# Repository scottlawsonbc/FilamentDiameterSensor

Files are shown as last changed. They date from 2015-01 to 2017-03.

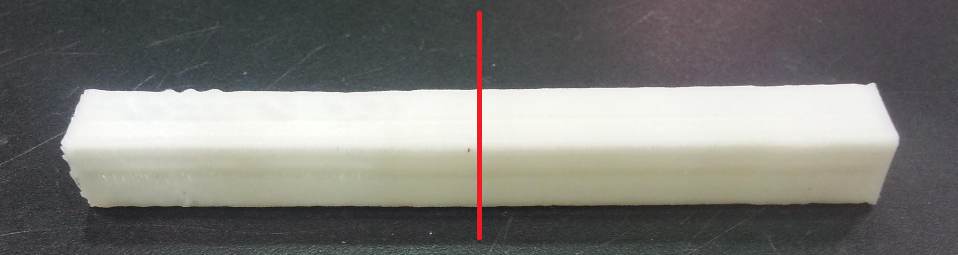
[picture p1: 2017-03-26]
pictures/surface-finish-quality-print.png

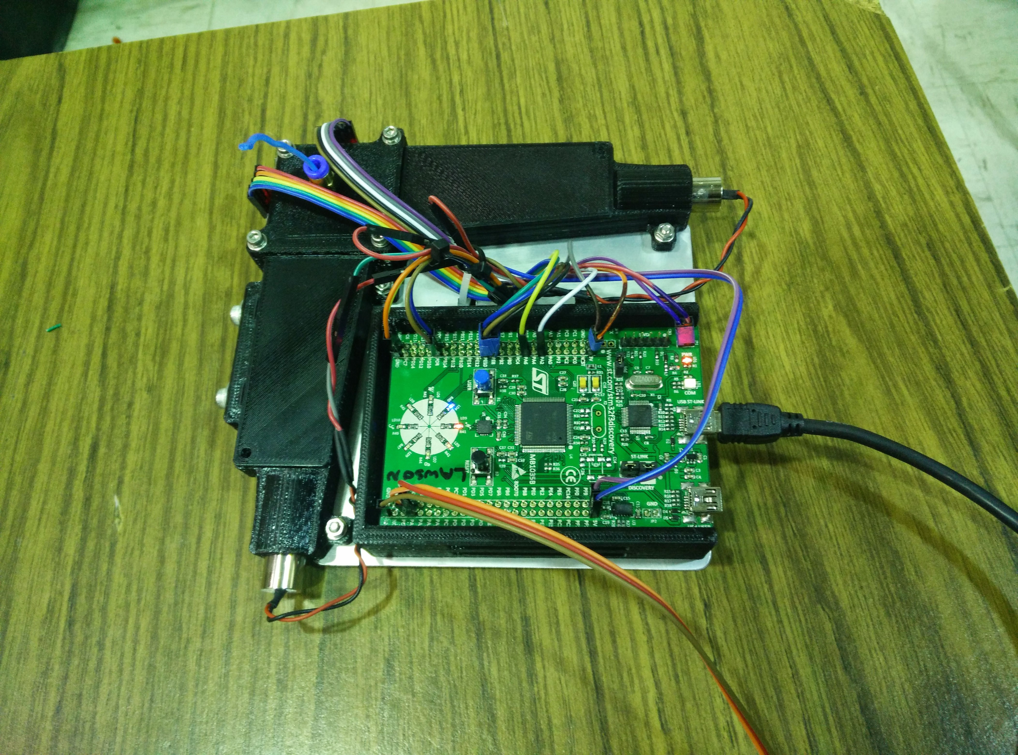
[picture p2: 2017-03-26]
pictures/printer-integrated-unattached.jpg

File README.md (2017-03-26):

# FilamentDiameterSensor

ENPH 459 - Engineering Physics Project I
----------------------------------------
A Non-contact Diameter Measurement Device for 3D Printers and Filament Manufacturing

### File Organization ###

1.  *Arduino* - 
    Initial prototype was implemented for Arduino.

2.  *Code* - 
    Includes the rest of the project's (non-MATLAB) code. Several versions of the shadow-simulator, a fork of the printer firmware Marlin(modified to interface with the filament sensor), and the sensor's firmware to be run on a STM32F3 development board.
    
3.  *Eagle* - 
    PCB layout files for the photodiode array (TSL1402CL) breakout board.
    
4.  *Matlab* - 
    Matlab script used to measure the relative print quality based on the roughness of vertical printed edges.

5.  *Pictures* - 
    Pictures from the sensor development and print quality testing.

6.  *Reference Documents* - 
    Documentation for the STM32F3 development board, the linear photodiode array used in the sensor, and the prototype sensor.
    
7.  *Solidworks* - 
    All 3D design for the sensor, mostly Solidworks with some .STL-rasterized models for 3D printing.

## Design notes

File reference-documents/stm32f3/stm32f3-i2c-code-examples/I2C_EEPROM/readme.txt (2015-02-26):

/**
  @page I2C_EEPROM  How to use the I2C to drive an EEPROM memory
  
  @verbatim
  ******************** (C) COPYRIGHT 2014 STMicroelectronics *******************
  * @file    I2C/I2C_EEPROM/readme.txt 
  * @author  MCD Application Team
  * @version V1.1.1
  * @date    31-October-2014
  * @brief   Description of the I2C and M24Mxx or M24Lxx EEPROM communication example.
  ******************************************************************************
  *
  * Licensed under MCD-ST Liberty SW License Agreement V2, (the "License");
  * You may not use this file except in compliance with the License.
  * You may obtain a copy of the License at:
  *
  *        http://www.st.com/software_license_agreement_liberty_v2
  *
  * Unless required by applicable law or agreed to in writing, software 
  * distributed under the License is distributed on an "AS IS" BASIS, 
  * WITHOUT WARRANTIES OR CONDITIONS OF ANY KIND, either express or implied.
  * See the License for the specific language governing permissions and
  * limitations under the License.
  *   
  ******************************************************************************
   @endverbatim

@par Example Description 

This firmware provides a basic example of how to use the I2C firmware library and
an associate I2C EEPROM driver to communicate with an I2C EEPROM device (here the
example is interfacing with M24M01 or M24LR64 EEPROM)

I2C peripheral is configured in Master transmitter during write operation and in
Master receiver during read operation from I2C EEPROM. 

The peripheral used is I2C2 but can be configured by modifying the defines values
in stm32303c_eval.h file.
The maximum speed of communication with M24M01 EEPROM is 1MHz and with M24LR64 is 400kHz.
The speed of communication is configured by setting the value of sEE_I2C_TIMING define
in stm32303c_eval_i2c_ee.h file.

For M24M01 devices all the memory is accessible through the two-bytes 
addressing mode and need to define block addresses. In this case, the physical 
address has to be defined according to the address pins (E0, E1) connection) and
memory block address (A16).

For M24LR64 devices all the memory is accessible through the two-bytes 
addressing mode and need to define block addresses. In this case, the physical 
address has to be defined according to the address pins (E1, E2) connection.

This address is defined in stm32303c_eval_i2c_ee.h. 
The EEPROM addresses where the program start the write and the read operations 
is defined in the main.c file. 

First, the content of Tx1Buffer is written to the sEE_WRITE_ADDRESS1 and the
written data are read. The written and the read buffers data are then compared.
Following the read operation, the program waits that the EEPROM reverts to its 
Standby state. A second write operation is, then, performed and this time, Tx2Buffer
is written to sEE_WRITE_ADDRESS2 which represents the address just after the last 
written one in the first write. After completion of the second write operation, the 
written data are read. The contents of the written and the read buffers are compared.

All transfers are managed in Polling mode by calling sEE_ReadBuffer() or 
sEE_WriteBuffer() function.

User should refer to stm32303c_eval.h file to select which EEPROM use in this example.
    
This example provides the possibility to use the LCD screen for messages display
(transfer status: Ongoing, PASSED, FAILED).
To enable this option uncomment the define ENABLE_LCD_MSG_DISPLAY in the main.c
file.

Note : By Default this example is configured to run with M24LR64 EEPROM. Refer to 
       stm32303c_eval_i2c_ee.h file to change supported EEPROM and update the
       I2C_TIMING. 
       
@par Directory contents 

  - I2C/I2C_EEPROM/stm32f30x_conf.h    Library Configuration file
  - I2C/I2C_EEPROM/stm32f30x_it.c      Interrupt handlers
  - I2C/I2C_EEPROM/stm32f30x_it.h      Interrupt handlers header file
  - I2C/I2C_EEPROM/main.c              Main program
  - I2C/I2C_EEPROM/main.h              Main program header file   
  - I2C/I2C_EEPROM/system_stm32f30x.c  STM32F30x system source file
  
@note The "system_stm32f30x.c" is generated by an automatic clock configuration 
      system and can be easily customized to your own configuration. 
      To select different clock setup, use the "STM32F30x_Clock_Configuration_V1.0.0.xls" 
      provided with the AN4152 package available on <a href="http://www.st.com/internet/mcu/family/141.jsp">  ST Microcontrollers </a>
      
@par Hardware and Software environment

  - This example runs on STM32F30x Devices.
  
  - This example has been tested with STMicroelectronics STM32303C-EVAL (STM32F30x)
    evaluation board and can be easily tailored to any other supported device 
    and development board. 

  - STM32303C-EVAL Set-up
    - When communicating with M24LR64 EEPROM, make sure that M24LR64 is inserted in CN1 connector and 
      JP5 and JP6 jumpers are fitted in position 1-2.
    - When communicating with M24M01 EEPROM, make sure that JP5 and JP6 jumpers are fitted in position 2-3
      and JP8 is fitted.
    
@par How to use it ? 

In order to make the program work, you must do the following :
 - Copy all source files from this example folder to the template folder under
   Projects\STM32F30x_StdPeriph_Templates
 - Open your preferred toolchain
 - Add the following file the project source list
    - Utilities\STM32_EVAL\STM32303C_EVAL\stm32303c_eval.c
    - Utilities\STM32_EVAL\STM32303C_EVAL\stm32303c_eval_lcd.c
    - Utilities\STM32_EVAL\STM32303C_EVAL\stm32303c_eval_i2c_ee.c
 - Before building the project please make sure that "USE_DEFAULT_TIMEOUT_CALLBACK" 
   define is removed from Preprocessor defines under C/C++ compiler settings.  
 - Rebuild all files and load your image into target memory
 - Run the example
    
 * <h3><center>&copy; COPYRIGHT STMicroelectronics</center></h3>
 */

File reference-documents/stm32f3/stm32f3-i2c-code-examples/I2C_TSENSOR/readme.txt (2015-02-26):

/**
  @page I2C_TSENSOR Communication between I2C and STTS751 Temperature sensor
  
  @verbatim
  ******************** (C) COPYRIGHT 2014 STMicroelectronics *******************
  * @file    I2C/I2C_TSENSOR/readme.txt 
  * @author  MCD Application Team
  * @version V1.1.1
  * @date    31-October-2014
  * @brief   Description of the I2C TSENSOR example.
  ******************************************************************************
  *
  * Licensed under MCD-ST Liberty SW License Agreement V2, (the "License");
  * You may not use this file except in compliance with the License.
  * You may obtain a copy of the License at:
  *
  *        http://www.st.com/software_license_agreement_liberty_v2
  *
  * Unless required by applicable law or agreed to in writing, software 
  * distributed under the License is distributed on an "AS IS" BASIS, 
  * WITHOUT WARRANTIES OR CONDITIONS OF ANY KIND, either express or implied.
  * See the License for the specific language governing permissions and
  * limitations under the License.
  *   
  ******************************************************************************
   @endverbatim

@par Example Description 

This example provides a description of how to use the I2C to communicate with 
an STTS751 (or a compatible device) I2C temperature sensor is mounted on the 
STM32303C-EVAL board and used to get instantaneous external temperature (-55°C to +125°C).
 
Thanks to STM32 I2C SMBus feature, we can easily monitor the temperature 
variations. This is managed by the SMBus Alert which is generating a dedicated 
interrupt informing the system that the temperature is out of the selected 
ranges.
The user can configure the TOS and THYS thanks to a dedicated define values in 
the code.

By default the STM32303C-EVAL demo are setting them to (see main.c file):
  
#define TEMPERATURE_THYS        0x14 /* 20°C */
#define TEMPERATURE_TOS         0x28 /* 40°C */

@par Directory contents 

  - I2C/I2C_TSENSOR/stm32f30x_conf.h    Library Configuration file
  - I2C/I2C_TSENSOR/stm32f30x_it.c      Interrupt handlers
  - I2C/I2C_TSENSOR/stm32f30x_it.h      Interrupt handlers header file
  - I2C/I2C_TSENSOR/main.c              Main program
  - I2C/I2C_TSENSOR/main.h              Main program header file   
  - I2C/I2C_TSENSOR/system_stm32f30x.c  STM32F30x system source file
  
@note The "system_stm32f30x.c" is generated by an automatic clock configuration 
      system and can be easily customized to your own configuration. 
      To select different clock setup, use the "STM32F30x_Clock_Configuration_V1.0.0.xls" 
      provided with the AN4152 package available on <a href="http://www.st.com/internet/mcu/family/141.jsp">  ST Microcontrollers </a>
         
@par Hardware and Software environment

  - This example runs on STM32F30x Devices.
  
  - This example has been tested with STMicroelectronics STM32303C-EVAL (STM32F30x)
    evaluation board and can be easily tailored to any other supported device 
    and development board. 

  - STM32303C-EVAL Set-up
    - Make sure that JP5 and JP6 jumpers are fitted in position 2-3.
    - Make sure that JP1 jumper is fitted.
    
@par How to use it ? 

In order to make the program work, you must do the following :
 - Copy all source files from this example folder to the template folder under
   Projects\STM32F30x_StdPeriph_Templates
 - Open your preferred toolchain 
 - Add the following file the project source list
    - Utilities\STM32_EVAL\STM32303C_EVAL\stm32303c_eval.c
    - Utilities\STM32_EVAL\STM32303C_EVAL\stm32303c_eval_lcd.c
    - Utilities\STM32_EVAL\STM32303C_EVAL\stm32303c_eval_i2c_tsensor.c
 - Before building the project please make sure that "USE_DEFAULT_TIMEOUT_CALLBACK" 
   define is removed from Preprocessor defines under C/C++ compiler settings. 
 - Rebuild all files and load your image into target memory
 - Run the example
   
 * <h3><center>&copy; COPYRIGHT STMicroelectronics</center></h3>
 */

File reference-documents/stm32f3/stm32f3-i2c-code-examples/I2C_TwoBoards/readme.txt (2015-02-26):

/**
  @page I2C_TwoBoards  I2C Communication Boards Data Exchange using CPAL Library
  
  @verbatim
  ******************** (C) COPYRIGHT 2014 STMicroelectronics *******************
  * @file    I2C/I2C_TwoBoards/readme.txt 
  * @author  MCD Application Team
  * @version V1.1.1
  * @date    31-October-2014
  * @brief   Description of the CPAL Two Boards communication example.
  ******************************************************************************
  *
  * Licensed under MCD-ST Liberty SW License Agreement V2, (the "License");
  * You may not use this file except in compliance with the License.
  * You may obtain a copy of the License at:
  *
  *        http://www.st.com/software_license_agreement_liberty_v2
  *
  * Unless required by applicable law or agreed to in writing, software 
  * distributed under the License is distributed on an "AS IS" BASIS, 
  * WITHOUT WARRANTIES OR CONDITIONS OF ANY KIND, either express or implied.
  * See the License for the specific language governing permissions and
  * limitations under the License.
  *   
  ******************************************************************************
   @endverbatim

@par Example Description 

This example shows how to use the CPAL library to control I2C devices and 
communicate between two different boards.

To use this example, you need to load the same software into two STM32 boards
(let's call them  Board A and Board B) then connect these two boards through I2C
lines and Gnd.

*------------------------------------------------------------------------------*
|                BOARD A                                BOARD B                |
|         ____________________                   ____________________          |
|        |                    |                 |                    |         |
|        |                    |                 |                    |         | 
|        |     __________     |                 |     __________     |         |
|        |    |I2C Device|____|_______SCL_______|____|I2C Device|    |         |
|        |    |__________|____|_______SDA_______|____|__________|    |         |
|        |                    |                 |                    |         |
|        |                    |                 |                    |         |
|        |  LEFT       RIGHT  |                 |  LEFT       RIGHT  |         |
|        |   _           _    |                 |   _           _    |         |
|        |  |_|         |_|   |                 |  |_|         |_|   |         |
|        |                    |                 |                    |         |
|        |             GND O--|-----------------|--O GND             |         |
|        |____________________|                 |____________________|         |
|                                                                              |
|                                                                              |
*------------------------------------------------------------------------------*

The example software perform the following actions:
 - At startup, Boards A & B are both in slave receiver mode and wait for messages 
   to be received.
 - When a push button is pressed, for example on Board A, the master transmitter 
   mode is activated and a message is sent to Board B containing identification 
   of the action relative to the push button.
 - Once a message is correctly sent, Board A activates the master transmitter mode 
   permanently and disables the slave receiver mode.
 - Once a message is received and correctly recognized, Board B activate the
   receiver mode and disable the transmitter mode. (push buttons interrupts are
   still active but message sending is disabled).
 - According to the push button pressed, a value is affected to a Timer which 
   generates periodic high priority interrupts. At each interrupt, a status message
   is sent to Board B. The period of Timer interrupts is variable depending on
   the push button pressed.    
 - When LEFT is pressed Board A send specific message (tSignal1) to Board B and set 
   the period of Timer to 1.5 seconds. When RIGHT is pressed specific message (tSignal2)
   is sent and the period of Timer is set to 0.305 seconds.

For each event (message received, message transmitted, error occur ...) a 
relative information is displayed on the LCD screen. When the same event is 
repeated, the line color is switched to highlight the event occurrence.

the Mode of Board (transmitter or receiver) is monitored by LEDs:
      - LED2 is toggling when transmitter mode is activated.
      - LED3 is toggling when receiver mode is activated. 

LED1 and LED4 are toggling by an interrupt generated by TIM6 each 50ms.

The programming model of I2C communication can be selected (DMA or Interrupt) in 
cpal_conf.h file by commenting or uncommenting these defines in Section 2 (Transfer
Options Configuration):
              #define CPAL_I2C_DMA_PROGMODEL
              #define CPAL_I2C_IT_PROGMODEL
Note : Only one define must selected. If these two defines are uncommented DMA Programming 
model is selected and the code size of this example will increase.

** UserCallbacks :

   - CPAL_TIMEOUT_UserCallback : This Callback is called to manage timeout error.
      In this Callback I2C device is reinitialized.
      
   - CPAL_I2C_ERR_UserCallback : This Callback is called to manage Device error .  
      In this Callback I2C device is reinitialized.
      Note: 
      If you want to generate an I2C error, you can disconnect I2C_SCL/I2C_SDA connector.
      In this case the I2C communication will be corrupted and the CPAL I2C error callbacks
      will be entered. If you fit back the jumper or connector, the communication should be 
      recovered immediately thanks to CPAL error management. 
      
   - CPAL_I2C_TXTC_UserCallback : This Callback is called when Write operation 
      is completed. In this Callback only information relative to communication 
      are displayed on LCD screen.
      
   - CPAL_I2C_RXTC_UserCallback : This Callback is called when Read operation 
      is completed. In this Callback received data are compared and transfer 
      status is displayed on LCD screen.

@par Directory contents 

  - I2C/I2C_TwoBoards/stm32f30x_conf.h                   Library Configuration file
  - I2C/I2C_TwoBoards/stm32f30x_it.c                     Interrupt handlers
  - I2C/I2C_TwoBoards/stm32f30x_it.h                     Interrupt handlers header file
  - I2C/I2C_TwoBoards/main.c                             Main program
  - I2C/I2C_TwoBoards/main.h                             Main program header file   
  - I2C/I2C_TwoBoards/system_stm32f30x.c                 STM32F30x system source file
  - I2C/I2C_TwoBoards/stm32f30x_i2c_cpal_conf.h          CPAL Library Configuration file
  - I2C/I2C_TwoBoards/stm32f30x_i2c_cpal_usercallback.c  CPAL Usercallbacks definition
  
@note The "system_stm32f30x.c" is generated by an automatic clock configuration 
      system and can be easily customized to your own configuration. 
      To select different clock setup, use the "STM32F30x_Clock_Configuration_V1.0.0.xls" 
      provided with the AN4152 package available on <a href="http://www.st.com/internet/mcu/family/141.jsp">  ST Microcontrollers </a>
        
@par Hardware and Software environment

  - This example runs on STM32F30x Devices.
  
  - This example has been tested with STMicroelectronics STM32303C-EVAL (STM32F30x)
    evaluation board and can be easily tailored to any other supported device 
    and development board. 

 - The same example should be loaded in two evaluation boards.
    
 - STM32303C-EVAL Set-up :
   Then these two boards should be connected as follows:
     - Connect I2C2 SCL pin (PF6) to I2C2 SCL pin (PF6)
     - Connect I2C2 SDA pin (PA10) to I2C2 SDA pin (PA10)
     - Connect Gnd pins of two boards.
    
@par How to use it ? 

In order to make the program work, you must do the following :
 - Copy all source files from this example folder to the template folder under
   Projects\STM32F30x_StdPeriph_Templates
 - Open your preferred toolchain 
 - Add the following files the project source list
     - Libraries\STM32F30x_I2C_CPAL_Driver\src\stm32f30x_i2c_cpal.c
     - Libraries\STM32F30x_I2C_CPAL_Driver\src\stm32f30x_i2c_cpal_hal.c
     - Projects\STM32F30x_StdPeriph_Templates\stm32f30x_i2c_cpal_usercallback.c
     - Utilities\STM32_EVAL\STM32303C_EVAL\stm32303c_eval.c
     - Utilities\STM32_EVAL\STM32303C_EVAL\stm32303c_eval_lcd.c
 - Rebuild all files and load your image into target memory
 - Run the example
    
 * <h3><center>&copy; COPYRIGHT STMicroelectronics</center></h3>
 */

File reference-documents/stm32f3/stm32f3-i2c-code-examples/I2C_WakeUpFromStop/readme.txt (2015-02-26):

/**
  @page I2C_WakeUpFromStop I2C WakeUp from stop mode
  
  @verbatim
  ******************** (C) COPYRIGHT 2014 STMicroelectronics *******************
  * @file    I2C/I2C_WakeUpFromStop/readme.txt 
  * @author  MCD Application Team
  * @version V1.1.1
  * @date    31-October-2014
  * @brief   Description of the Wake Up from Stop mode example.
  ******************************************************************************
  *
  * Licensed under MCD-ST Liberty SW License Agreement V2, (the "License");
  * You may not use this file except in compliance with the License.
  * You may obtain a copy of the License at:
  *
  *        http://www.st.com/software_license_agreement_liberty_v2
  *
  * Unless required by applicable law or agreed to in writing, software 
  * distributed under the License is distributed on an "AS IS" BASIS, 
  * WITHOUT WARRANTIES OR CONDITIONS OF ANY KIND, either express or implied.
  * See the License for the specific language governing permissions and
  * limitations under the License.
  *
  ******************************************************************************
  @endverbatim

@par Example Description 

This example shows how to use the WakeUp from STOP feature of I2C device using 
the CPAL library. This example requires two boards, one configured in master mode
and another one configured in slave mode.

The I2C of the slave board is configured as slave device which enters in STOP mode
after activating The WakeUp from stop ability. 

The master board is used to WakeUp the slave board from STOP. By pushing the key Button
of the master board, the I2C device initialize a communication by sending a Start condition
followed by the address of slave device. 

The slave device is woken Up from STOP if it recognizes its own address. 
The received data is checked and the result is displayed on LCD. 

This procedure is repeated infinitely.

The main.h file contains defines(I2C_MASTER, I2C_SLAVE) that select the type of 
the board(master or slave).

Note: Before entering STOP The I2C clock source must be set to HSI.

@par Directory contents 

  - I2C/I2C_WakeUpFromStop/stm32f30x_conf.h                    Library Configuration file
  - I2C/I2C_WakeUpFromStop/stm32f30x_it.c                      Interrupt handlers
  - I2C/I2C_WakeUpFromStop/stm32f30x_it.h                      Interrupt handlers header file
  - I2C/I2C_WakeUpFromStop/main.c                              Main program
  - I2C/I2C_WakeUpFromStop/main.h                              Main program header file 
  - I2C/I2C_WakeUpFromStop/system_stm32f30x.c                  STM32F30x system source file
  - I2C/I2C_TwoBoards/stm32f30x_i2c_cpal_conf.h                CPAL Library Configuration file
  - I2C/I2C_WakeUpFromStop/stm32f30x_i2c_cpal_usercallback.c   CPAL UserCallback source file
  
@note The "system_stm32f30x.c" is generated by an automatic clock configuration 
      system and can be easily customized to your own configuration. 
      To select different clock setup, use the "STM32F30x_Clock_Configuration_V1.0.0.xls" 
      provided with the AN4152 package available on <a href="http://www.st.com/internet/mcu/family/141.jsp">  ST Microcontrollers </a>
   
@par Hardware and Software environment

  - This example runs on STM32F30x Devices.
  
  - This example has been tested with STMicroelectronics STM32303C-EVAL (STM32F30x)
    evaluation board and can be easily tailored to any other supported device 
    and development board.

  - STM32303C-EVAL Set-up
    - Two boards must be used to run this example. The type of the board is selected
      by comments or uncomments defines (I2C_MASTER, I2C_SLAVE) located in main.h file.
    - These two boards should be connected as follow after loading the example:
     - Connect I2C2 SCL pin (PF6) to I2C2 SCL pin (PF6)
     - Connect I2C2 SDA pin (PA10) to I2C2 SDA pin (PA10)
     - Connect Gnd pins of two boards.
    - Make sure that JP5 and JP6 jumpers are fitted in position 2-3.

@par How to use it ? 

In order to make the program work, you must do the following :
 - Copy all source files from this example folder to the template folder under
   Projects\STM32F30x_StdPeriph_Templates
 - Open your preferred toolchain
 - Add the following files the project source list
     - Libraries\STM32F30x_I2C_CPAL_Driver\src\stm32f30x_i2c_cpal.c
     - Libraries\STM32F30x_I2C_CPAL_Driver\src\stm32f30x_i2c_cpal_hal.c
     - Projects\STM32F30x_StdPeriph_Templates\stm32f30x_i2c_cpal_usercallback.c
     - Utilities\STM32_EVAL\STM32303C_EVAL\stm32303c_eval.c
     - Utilities\STM32_EVAL\STM32303C_EVAL\stm32303c_eval_lcd.c  
 - Rebuild all files and load your image into target memory
 - Run the example

 * <h3><center>&copy; COPYRIGHT STMicroelectronics</center></h3>
 */

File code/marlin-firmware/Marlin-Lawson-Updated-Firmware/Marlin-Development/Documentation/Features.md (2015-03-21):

# Features

*   Interrupt based movement with real linear acceleration
*   High steprate
*   Look ahead (Keep the speed high when possible. High cornering speed)
*   Interrupt based temperature protection
*   Preliminary support for [Matthew Roberts Advance Algorithm](http://reprap.org/pipermail/reprap-dev/2011-May/003323.html)
*   Full endstop support
*   SD Card support
*   SD Card folders (works in pronterface)
*   SD Card autostart support
*   LCD support (ideally 20x4)
*   LCD menu system for autonomous SD card printing, controlled by an click-encoder.
*   EEPROM storage of e.g. max-velocity, max-acceleration, and similar variables
*   many small but handy things originating from bkubicek's fork.
*   Arc support
*   Temperature oversampling
*   Dynamic Temperature setpointing aka "AutoTemp"
*   Support for [QTMarlin](https://github.com/bkubicek/QTMarlin), a very beta GUI for PID-tuning and velocity-acceleration testing. 
*   Endstop trigger reporting to the host software.
*   Updated sdcardlib
*   Heater power reporting. Useful for PID monitoring.
*   PID tuning
*   [CoreXY kinematics](www.corexy.com/theory.html)
*   Delta kinematics
*   SCARA kinematics
*   Dual X-carriage support for multiple extruder systems
*   Configurable serial port to support connection of wireless adaptors.
*   Automatic operation of extruder/cold-end cooling fans based on nozzle temperature
*   RC Servo Support, specify angle or duration for continuous rotation servos.
*   Bed Auto Leveling.
*   Support for a filament diameter sensor, which adjusts extrusion volume

The default baudrate is 250000. This baudrate has less jitter and hence errors than the usual 115200 baud, but is less supported by drivers and host-environments.

## Differences and additions to the already good Sprinter firmware

### Look-ahead

Marlin has look-ahead. While sprinter has to break and re-accelerate at each corner,
lookahead will only decelerate and accelerate to a velocity,
so that the change in vectorial velocity magnitude is less than the xy_jerk_velocity.
This is only possible, if some future moves are already processed, hence the name.
It leads to less over-deposition at corners, especially at flat angles.

### Arc support

Slic3r can find curves that, although broken into segments, were ment to describe an arc.
Marlin is able to print those arcs. The advantage is the firmware can choose the resolution,
and can perform the arc with nearly constant velocity, resulting in a nice finish.
Also, less serial communication is needed.

### Temperature Oversampling

To reduce noise and make the PID-differential term more useful, 16 ADC conversion results are averaged.

### AutoTemp

If your gcode contains a wide spread of extruder velocities, or you realtime change the building speed, the temperature should be changed accordingly.
Usually, higher speed requires higher temperature.
This can now be performed by the AutoTemp function
By calling M109 S<mintemp> B<maxtemp> F<factor> you enter the autotemp mode.

You can leave it by calling M109 without any F.
If active, the maximal extruder stepper rate of all buffered moves will be calculated, and named "maxerate" [steps/sec].
The wanted temperature then will be set to t=tempmin+factor*maxerate, while being limited between tempmin and tempmax.
If the target temperature is set manually or by gcode to a value less then tempmin, it will be kept without change.
Ideally, your gcode can be completely free of temperature controls, apart from a M109 S T F in the start.gcode, and a M109 S0 in the end.gcode.

### EEPROM

If you know your PID values, the acceleration and max-velocities of your unique machine, you can set them, and finally store them in the EEPROM.
After each reboot, it will magically load them from EEPROM, independent what your Configuration.h says.

### LCD Menu

If your hardware supports it, you can build yourself a LCD-CardReader+Click+encoder combination. It will enable you to realtime tune temperatures,
accelerations, velocities, flow rates, select and print files from the SD card, preheat, disable the steppers, and do other fancy stuff.
One working hardware is documented here: http://www.thingiverse.com/thing:12663
Also, with just a 20x4 or 16x2 display, useful data is shown.

### SD card directories

If you have an SD card reader attached to your controller, also folders work now. Listing the files in pronterface will show "/path/subpath/file.g".
You can write to file in a subfolder by specifying a similar text using small letters in the path.
Also, backup copies of various operating systems are hidden, as well as files not ending with ".g".

### Autostart

If you place a file auto[0-9].g into the root of the sd card, it will be automatically executed if you boot the printer. The same file will be executed by selecting "Autostart" from the menu.
First *0 will be performed, than *1 and so on. That way, you can heat up or even print automatically without user interaction.

### Endstop trigger reporting

If an endstop is hit while moving towards the endstop, the location at which the firmware thinks that the endstop was triggered is outputed on the serial port.
This is useful, because the user gets a warning message.
However, also tools like QTMarlin can use this for finding acceptable combinations of velocity+acceleration.

### Coding paradigm

Not relevant from a user side, but Marlin was split into thematic junks, and has tried to partially enforced private variables.
This is intended to make it clearer, what interacts which what, and leads to a higher level of modularization.
We think that this is a useful prestep for porting this firmware to e.g. an ARM platform in the future.
A lot of RAM (with enabled LCD ~2200 bytes) was saved by storing char []="some message" in Program memory.
In the serial communication, a #define based level of abstraction was enforced, so that it is clear that
some transfer is information (usually beginning with "echo:"), an error "error:", or just normal protocol,
necessary for backwards compatibility.

### Interrupt based temperature measurements

An interrupt is used to manage ADC conversions, and enforce checking for critical temperatures.
This leads to less blocking in the heater management routine.

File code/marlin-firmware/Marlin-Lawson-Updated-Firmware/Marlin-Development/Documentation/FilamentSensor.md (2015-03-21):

Filament Sensor
---------------
Supports the use of a real time filament diameter sensor that measures the diameter of the filament going into the extruder and then adjusts the extrusion rate to compensate for filament that does not match what is defined in the g-code.  The diameter can also be displayed on the LCD screen. This potentially eliminates the need to measure filament diameter when changing spools of filament. Gcode becomes independent of the filament diameter. Can also compensate for changing diameter.

For examples of these sensors, see: http://www.thingiverse.com/thing:454584, https://www.youmagine.com/designs/filament-diameter-sensor, http://diy3dprinting.blogspot.com/2014/01/diy-filament-diameter-sensor.html. Any sensor which produces a voltage equivalent to the diameter in mm (i.e. 1v = 1mm) can be used. This provides a very simple interface and may encourage more innovation in this area.

4 new Mcodes are defined to set relevant parameters: M404, M405, M406, M407 - see above.

 Implements a delay buffer to handle the transit delay between where the filament is measured and when it gets to the extruder.

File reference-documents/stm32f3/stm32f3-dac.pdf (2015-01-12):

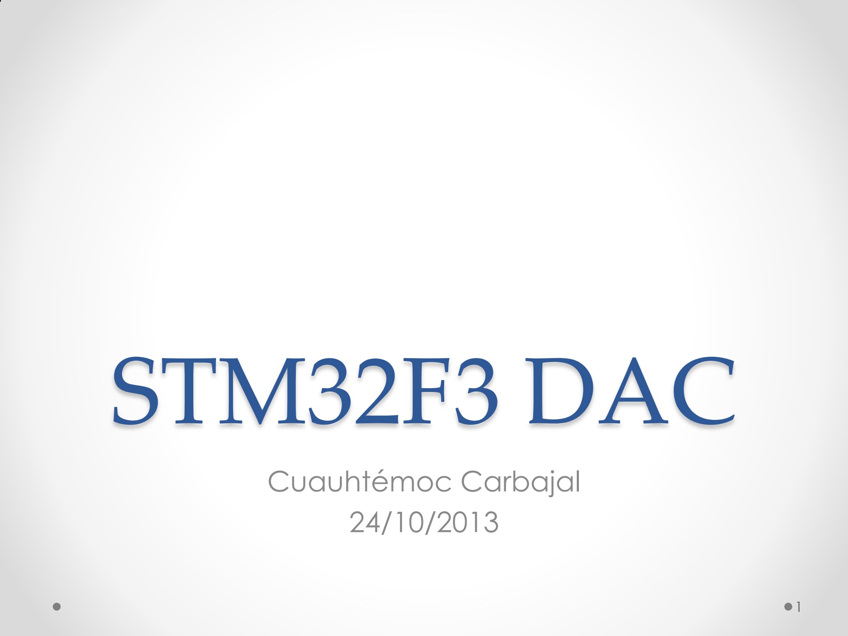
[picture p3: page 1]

# STM32F3 DAC

Cuauhtémoc Carbajal
24/10/2013

- The DAC module is a 12-bit, voltage output digital-to-analog converter.
- The DAC can be configured in 8- or 12-bit mode and may be used in conjunction with the DMA controller.
- In 12-bit mode, the data could be left- or right-aligned. An input reference voltage, VREF+ (shared with ADC) is available.
- The output can optionally be buffered for higher current drive.
- The devices features one DAC, DAC1, with two 12-bit channels:
- DAC1 channel output 1, DAC1_OUT1
- DAC1 channel output 2, DAC1_OUT2
- The two channels can be used independently or simultaneously when both channels are grouped together for synchronous update operations (dual mode).

- Left or right data alignment in 12-bit mode
- Synchronized update capability
- Noise-wave generation
- Triangular-wave generation
- Independent or simultaneous conversions (dual mode only)
- DMA capability for each channel
- DMA underrun error detection
- External triggers for conversion
- Programmable internal buffer
- Input voltage reference, VREF+

## Block Diagram

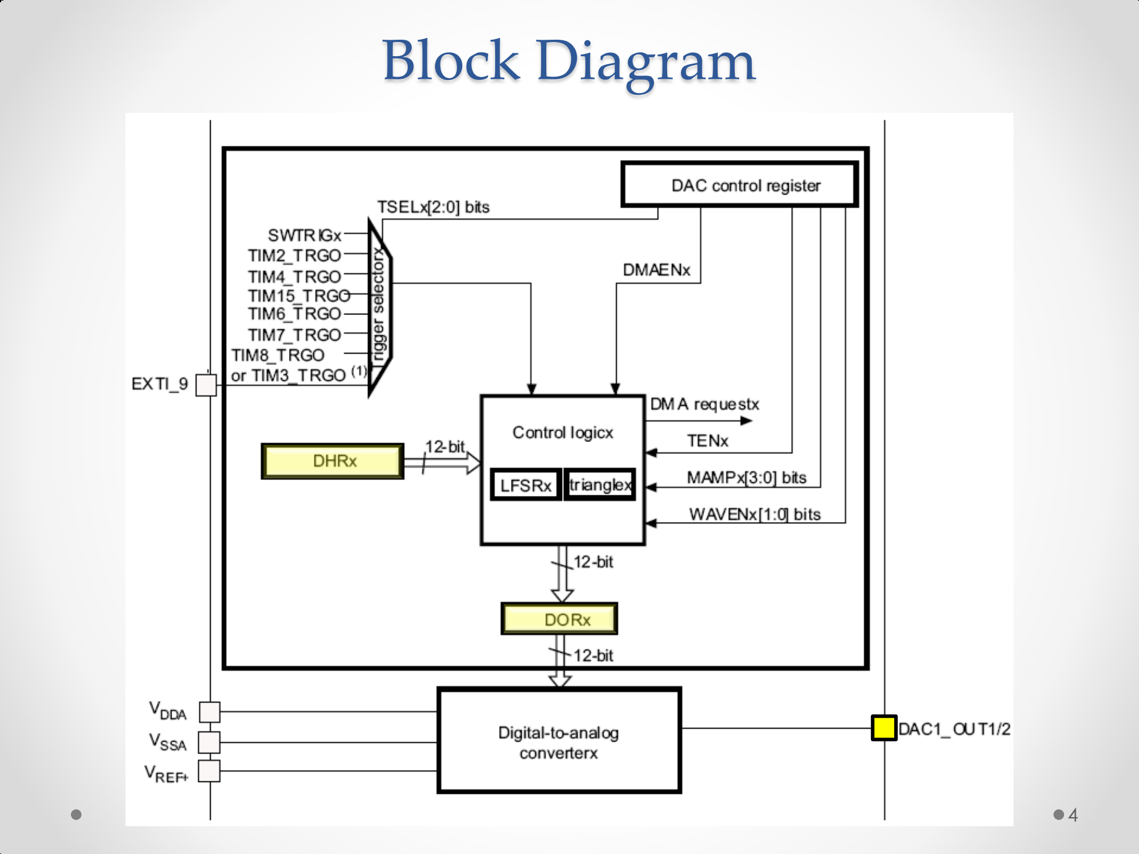
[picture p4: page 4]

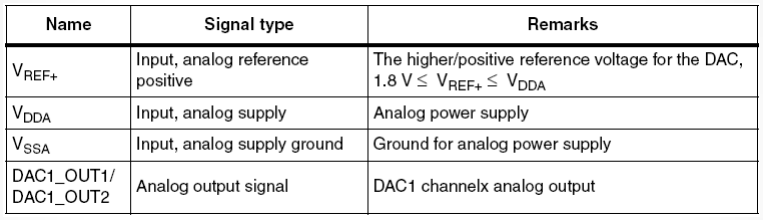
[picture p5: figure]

- Once DAC1 channelx is enabled, the corresponding GPIO pin (PA4 or PA5) is automatically connected to the analog converter output (DAC1_OUTx).
- In order to avoid parasitic consumption, the PA4 or PA5 pin should first be configured to analog (AIN).

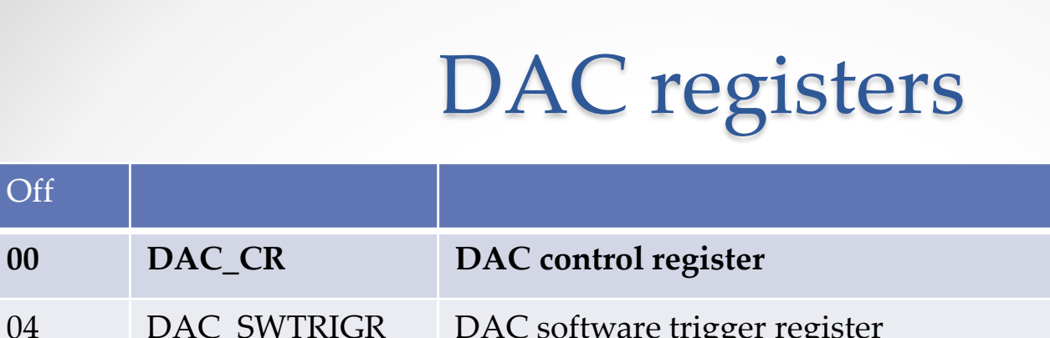
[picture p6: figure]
DAC registers; DAC_CR; DAC control register

Off

04 | DAC_SWTRIGR | DAC software trigger register
08 | DAC_DHR12R1 | DAC channel1 12-bit right-aligned data holding register
0C | DAC_DHR12L1 | DAC channel1 12-bit left aligned data holding register
10 | DAC_DHR8R1 | DAC channel1 8-bit right aligned data holding register
14 | DAC_DHR12R2 | DAC channel2 12-bit right-aligned data holding register
18 | DAC_DHR12L2 | DAC channel2 12-bit left aligned data holding register
1C | DAC_DHR8R2 | DAC channel2 8-bit right aligned data holding register
20 | DAC_DHR12RD | Dual DAC 12-bit right-aligned data holding register
24 | DAC_DHR12LD | DUAL DAC 12-bit left aligned data holding register
28 | DAC_DHR8RD | DUAL DAC 8-bit right aligned data holding register
2C | DAC_DOR1 | DAC channel1 data output register
30 | DAC_DOR2 | DAC channel2 data output register
34 | DAC_SR | DAC status register

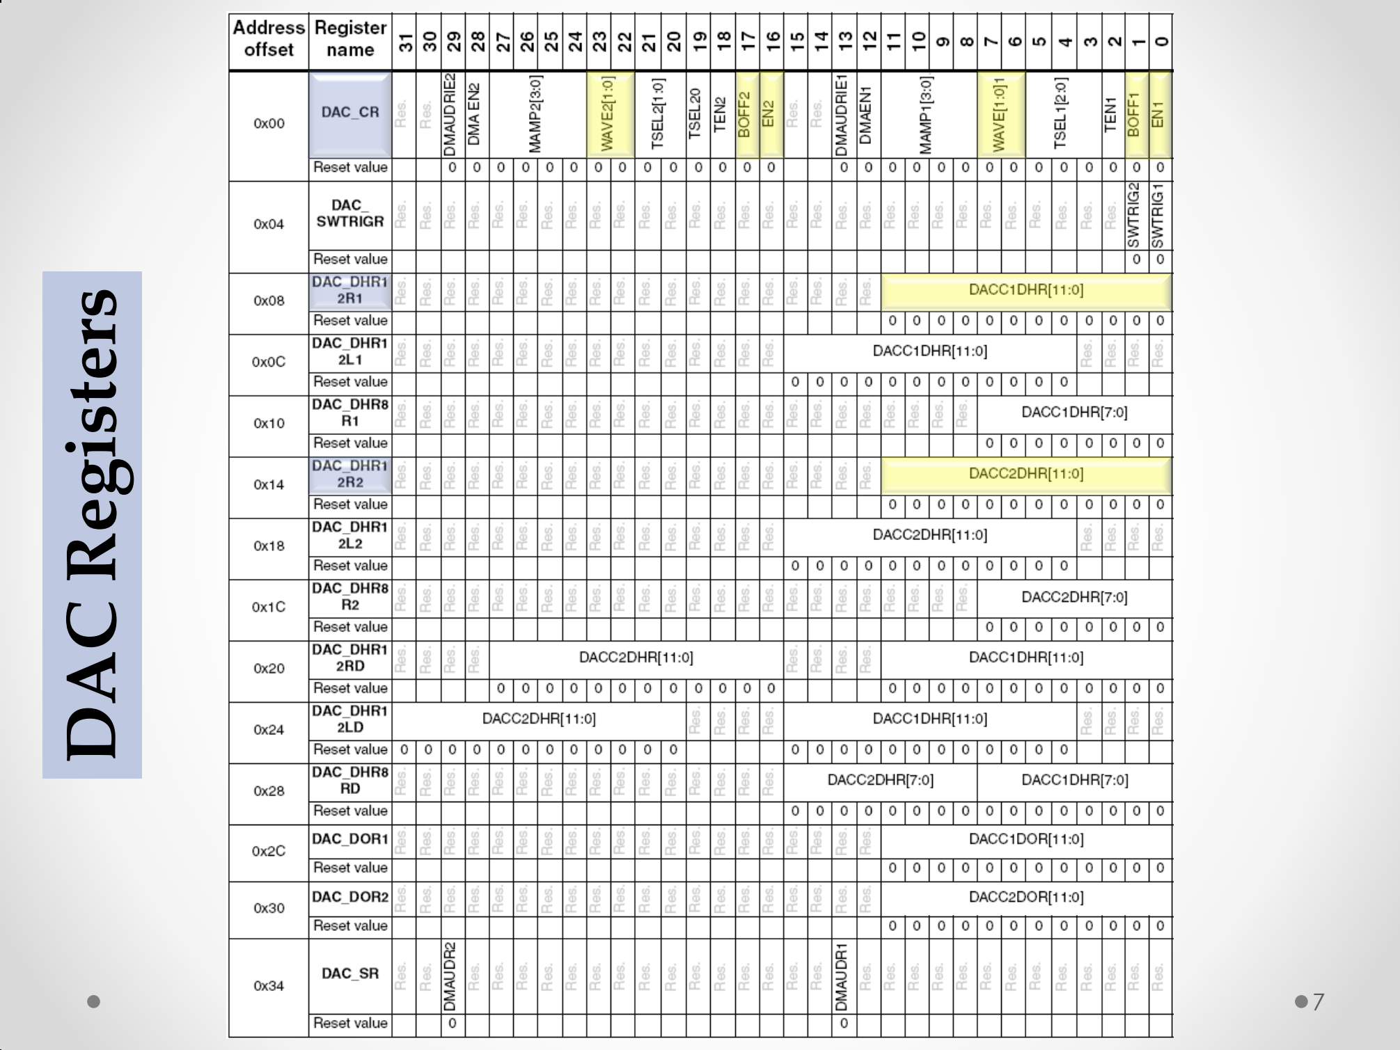
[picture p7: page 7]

## DAC Registers

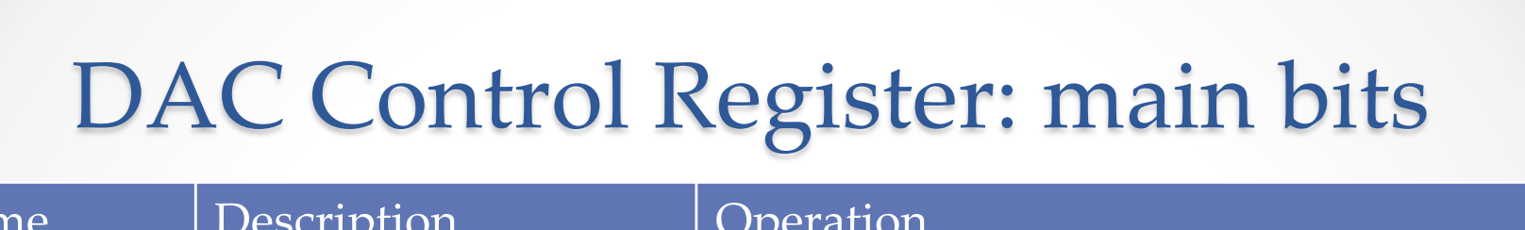
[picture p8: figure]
DAC Control Register: main bits

Name | Description | Operation
WAVEx[1:0] | DAC channelx noise/triangle wave generation enable | 00: Wave generation disabled 01: Noise wave generation enabled 1x: Triangle wave generation enabled
BOFFx | DAC channelx output buffer disable | 0: DAC channelx output buffer enabled 1: DAC channel1 output buffer disabled
ENx | DAC channel1 enable | 0: DAC channel1 disabled 1: DAC channel1 enabled

- The DAC channelx data output register (DAC_DORx) cannot be written directly.
- Any data transfer to the DAC channelx must be performed by loading the DAC_DHRx register (write to DAC_DHR8Rx, DAC_DHR12Lx, DAC_DHR12Rx).
- Data stored in the DAC_DHRx register are automatically transferred to the DAC_DORx register after one APB1 clock cycle, if no hardware trigger is selected (TENx bit in DAC_CR register is reset).

- Digital inputs are converted to output voltages on a linear conversion between 0 and VDDA.
- The analog output voltages on each DAC channel pin are determined by the following equation:

DAC output= VDD

DOR
4095

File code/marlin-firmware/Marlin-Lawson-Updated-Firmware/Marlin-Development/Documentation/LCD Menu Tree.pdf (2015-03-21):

# Marlin LCD Menu Tree

Main Menu | Tune Menu | Move Menu
Info screen | Main | Prepare
Tune | Speed | Move 10mm | Move Menu
Prepare | Nozzle | Move 1mm | Move axis
Control | Nozzle2 | Move 0.1mm | Move X
Pause print | Nozzle3 | | Move Y
Resume print | Bed | | Move Z
Stop print | Fan speed | Temperature Menu | Extruder
Print from SD | Flow | Control
Change SD card | Babystep X | Nozzle
No SD card | Babystep Y | Nozzle2
Init. SD card | Babystep Z | Nozzle3
| Change filament | Bed
| | Fan speed
| | Autotemp
| Prepare Menu | \002 Min
| Main | \002 Max | Preheat PLA
| Autostart | \002 Fact | Temperature
| Disable steppers | PID-P | Fan speed
| Auto home | PID-I | Nozzle
| Preheat PLA | PID-D | Bed
| Preheat ABS | PID-C | Store memory
| Cooldown | Preheat PLA conf
| Switch power off | Preheat ABS conf | Preheat ABS
Switch power on | Temperature
Move axis | Fan speed
| Motion Menu | Nozzle
| Control | Bed
Control Menu | Z Offset | Store memory
Main | Accel
Temperature | Vxy-jerk
Motion | Vz-jerk
LCD contrast | Ve-jerk
Retract | Vmax x
Store memory | Vmax y
Load memory | Vmax z
Restore failsafe | Vmax e
| Vmin
| VTrav min
SD Card Menu | Amax x
Main | Amax y
Refresh | Amax z
filenames | Amax e
| A-retract
| Xsteps/mm
| Ysteps/mm
| Zsteps/mm
| Esteps/mm
| Endstop abort

Retract Menu
Control
AutoRetr.
Retract mm
Retract F
Hop mm
UnRet +mm
UnRet F

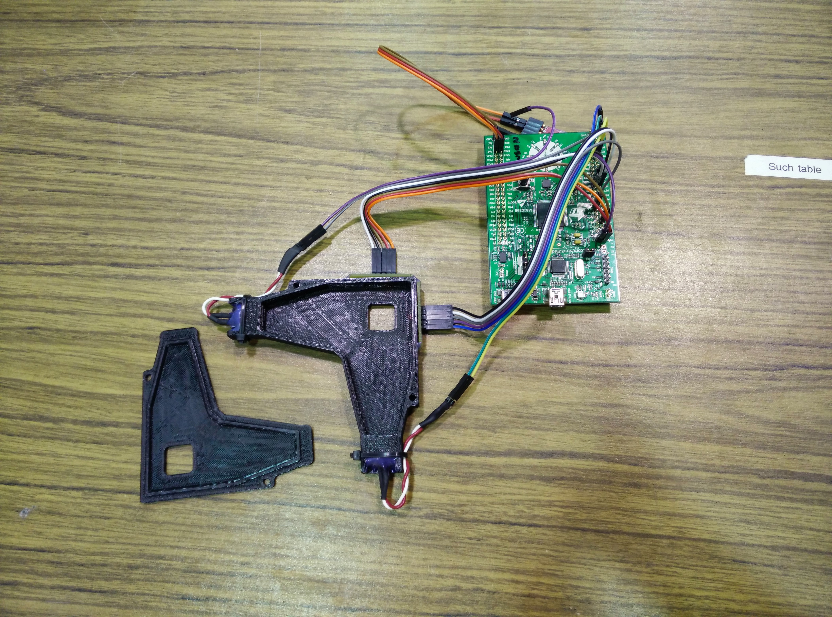
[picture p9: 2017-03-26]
pictures/first-two-axis-sensor.jpg

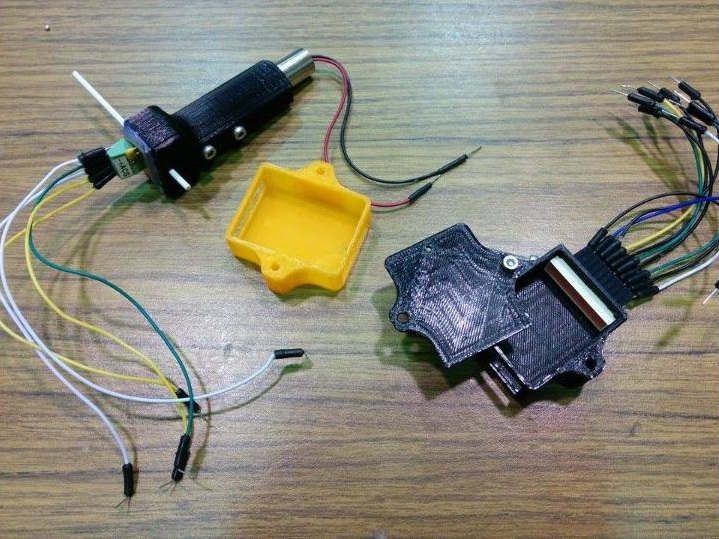
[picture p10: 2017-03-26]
pictures/single-axis-prototypes.jpg

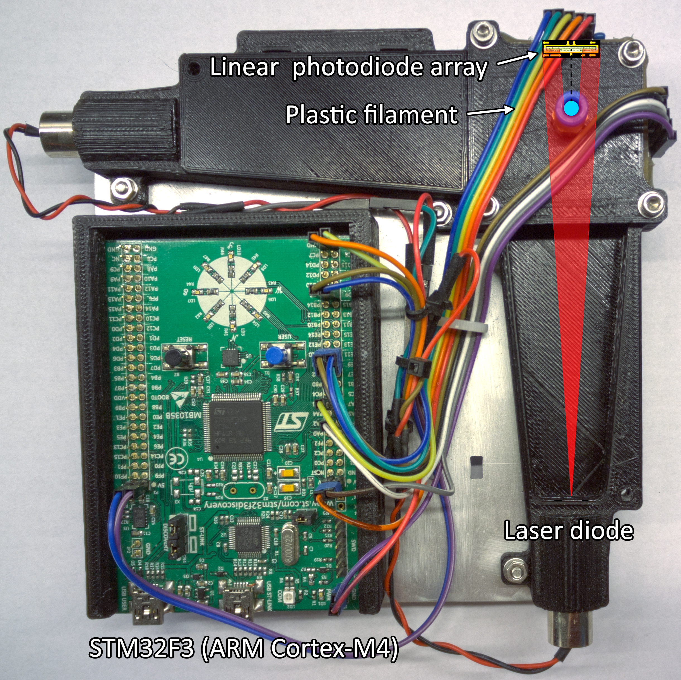
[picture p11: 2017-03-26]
pictures/filament-sensor.jpg

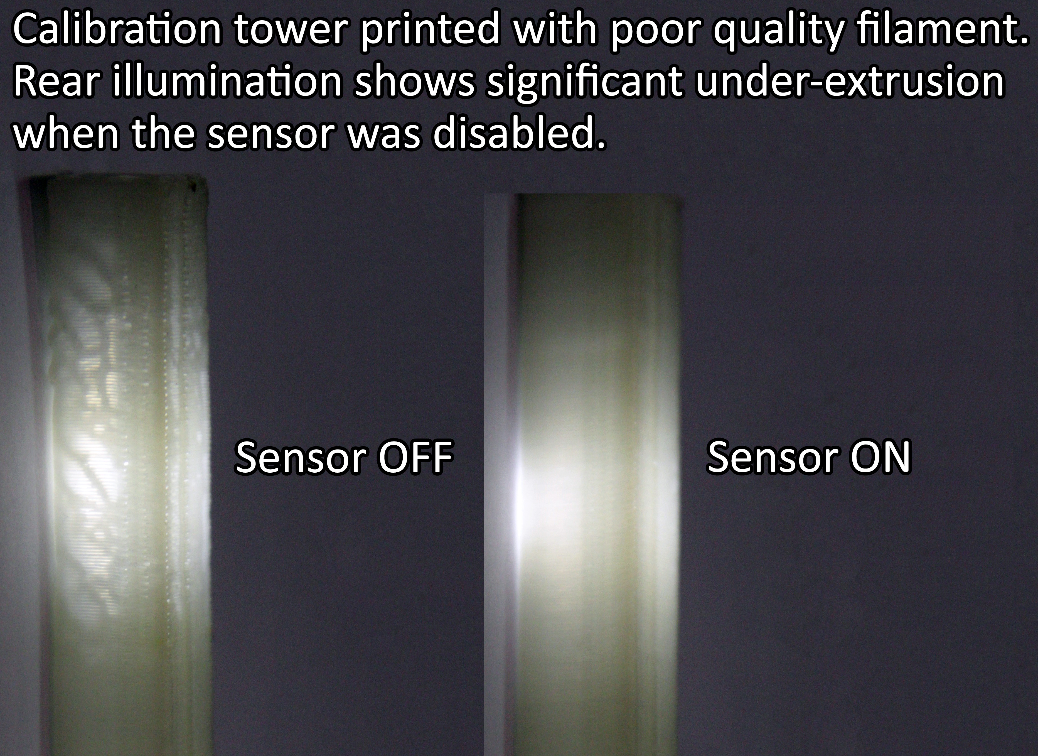
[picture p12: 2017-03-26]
pictures/tower-comparison-side-by-side.jpg

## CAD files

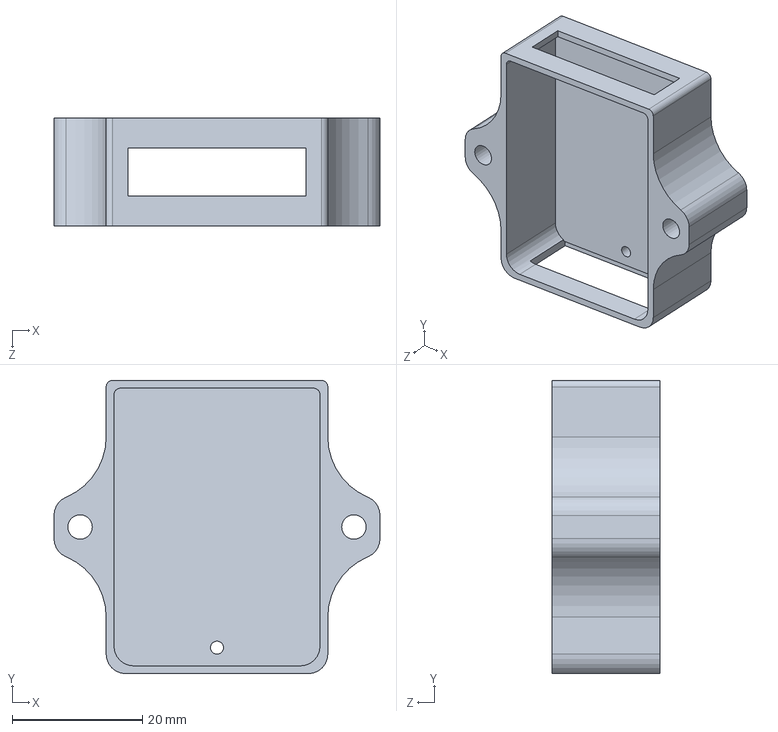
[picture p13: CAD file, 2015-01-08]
solidworks/single-axis-led-bar/main-section.SLDPRT
50.0 x 45.0 x 16.5 mm

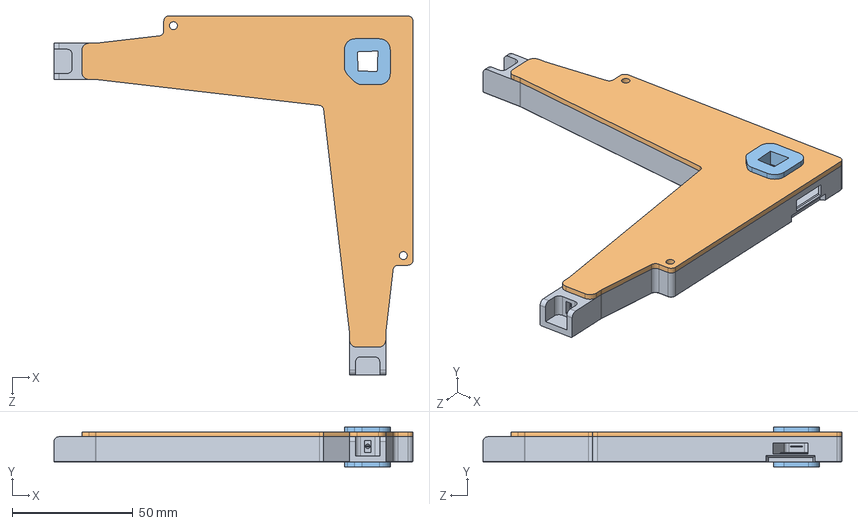
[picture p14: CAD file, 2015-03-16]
solidworks/2-axis-prototype/Assembly.SLDASM
148.5 x 16.5 x 148.5 mm
Chassis
Lid
Lid Insert x 2

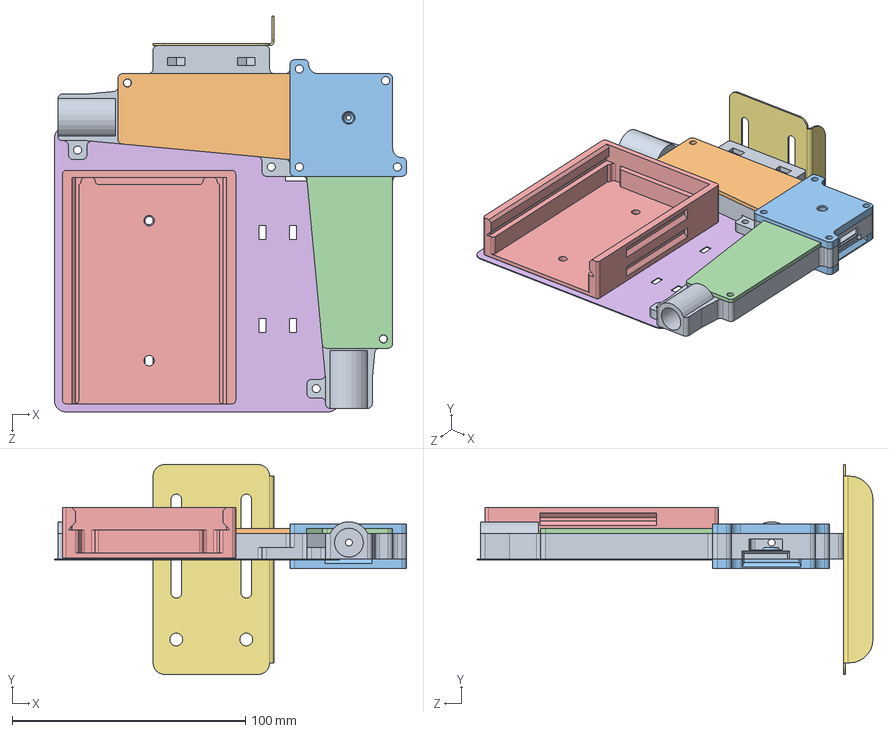
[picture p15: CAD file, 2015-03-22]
solidworks/printer-adapted-sensor/Assembly.SLDASM
151.0 x 90.0 x 169.7 mm
printer-adapted-chassis
printer-adapted-lid
printer-adapted-filament-attachment x 2
Mirrorprinter-adapted-lid
printer-adapted-circuit-case
printer-adapted-circuit-plate
printer-adapted-mounting-bracket

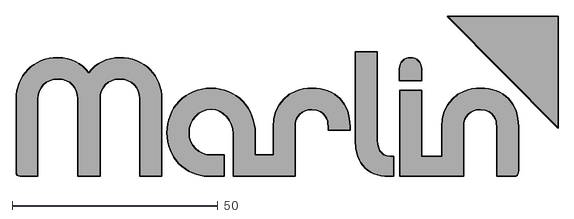
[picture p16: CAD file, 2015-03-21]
code/marlin-firmware/Marlin-Lawson-Updated-Firmware/Marlin-Development/Documentation/Logo/Marlin Logo.dxf
131.6 x 39.5

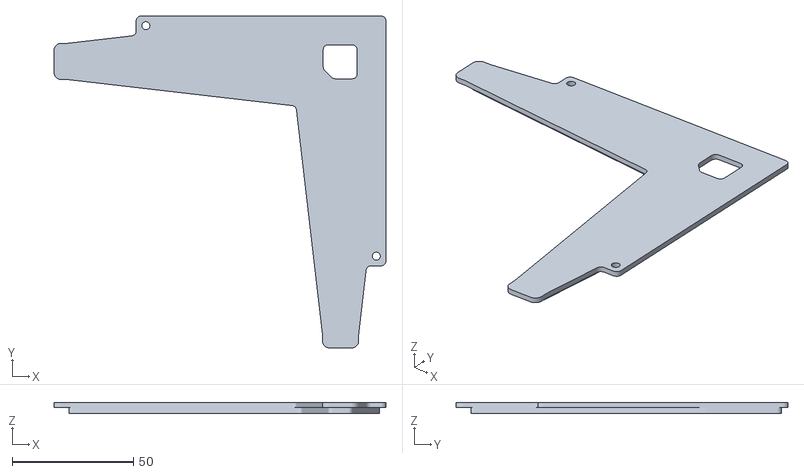
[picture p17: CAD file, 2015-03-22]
solidworks/2-axis-prototype/Lid-130mm.STL
137.0 x 137.0 x 4.40

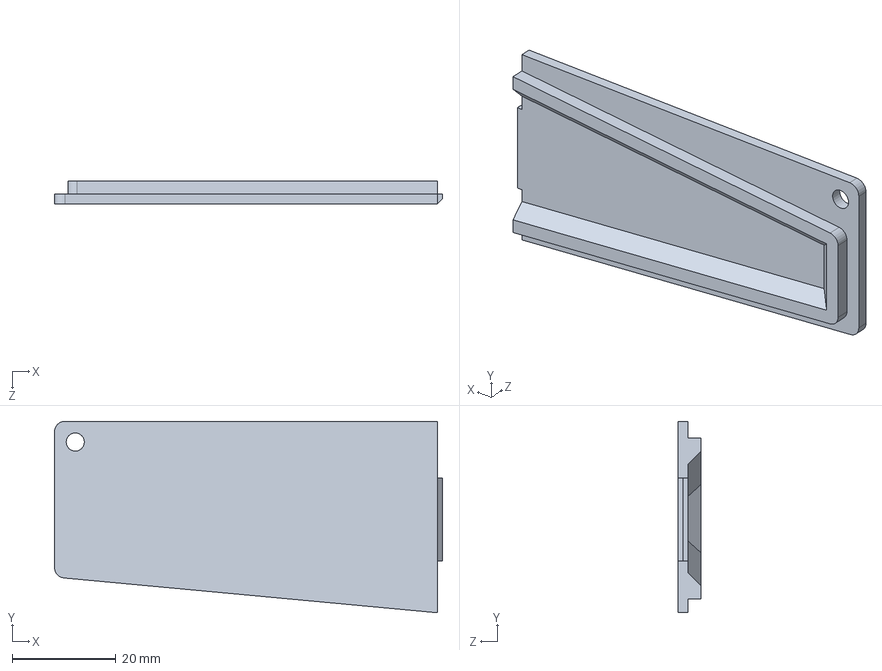
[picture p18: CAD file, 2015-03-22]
solidworks/printer-adapted-sensor/printer-adapted-lid.SLDPRT
74.7 x 36.9 x 4.50 mm

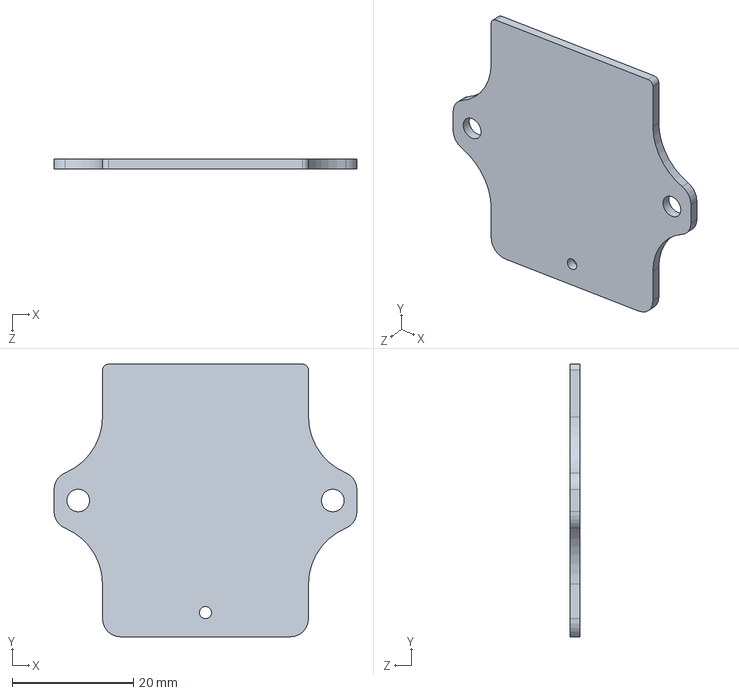
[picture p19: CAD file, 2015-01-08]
solidworks/single-axis-led-bar/top-section.SLDPRT
50.0 x 45.0 x 1.60 mm

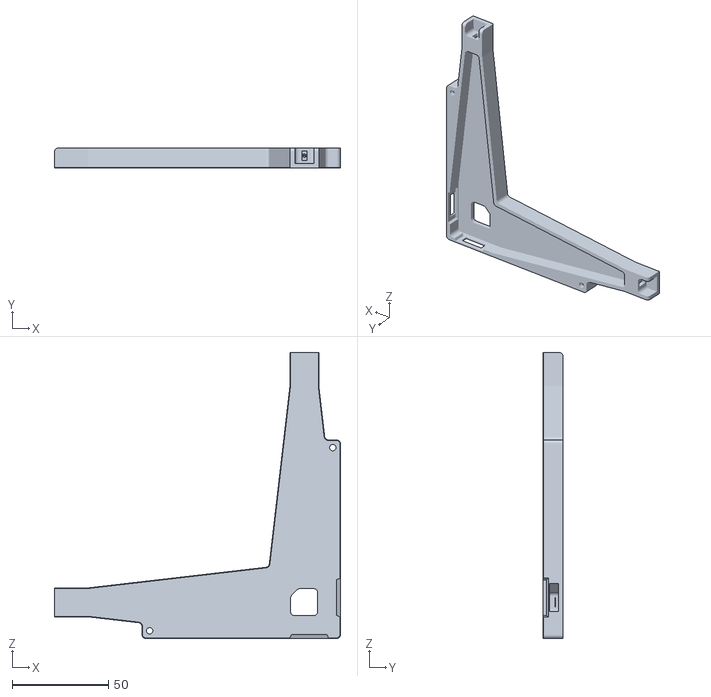
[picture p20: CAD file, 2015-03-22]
solidworks/2-axis-prototype/Chassis-130mm.STL
148.5 x 10.5 x 148.5

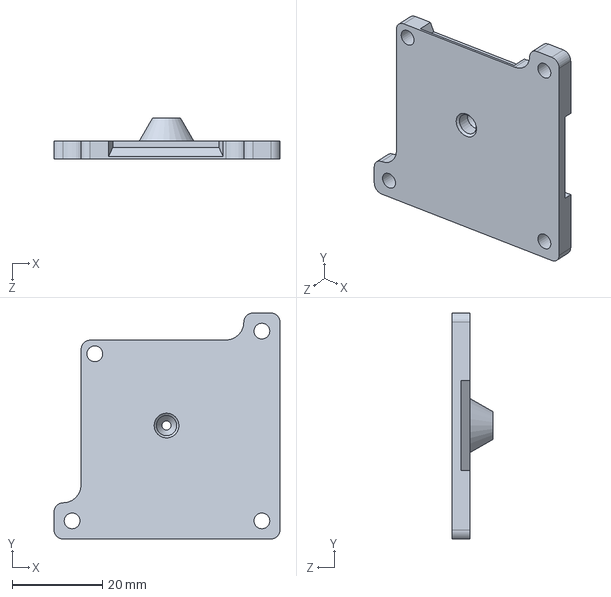
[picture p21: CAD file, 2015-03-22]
solidworks/printer-adapted-sensor/printer-adapted-filament-attachment.SLDPRT
50.0 x 50.0 x 9.00 mm

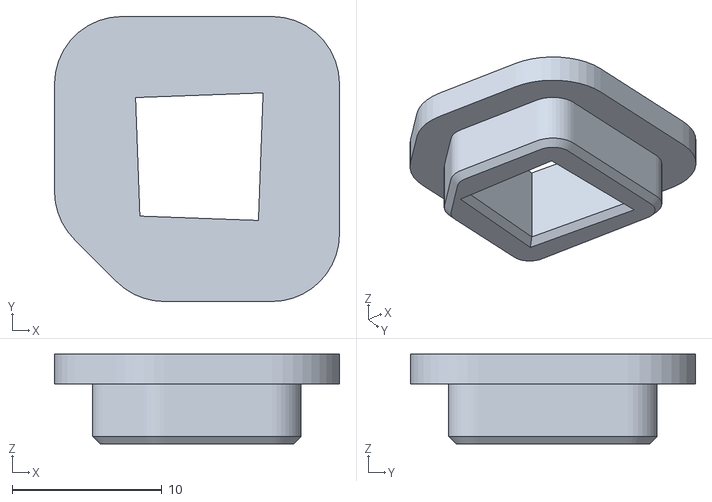
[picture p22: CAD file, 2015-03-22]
solidworks/2-axis-prototype/Lid-Insert-130mm.STL
19.0 x 19.0 x 6.00

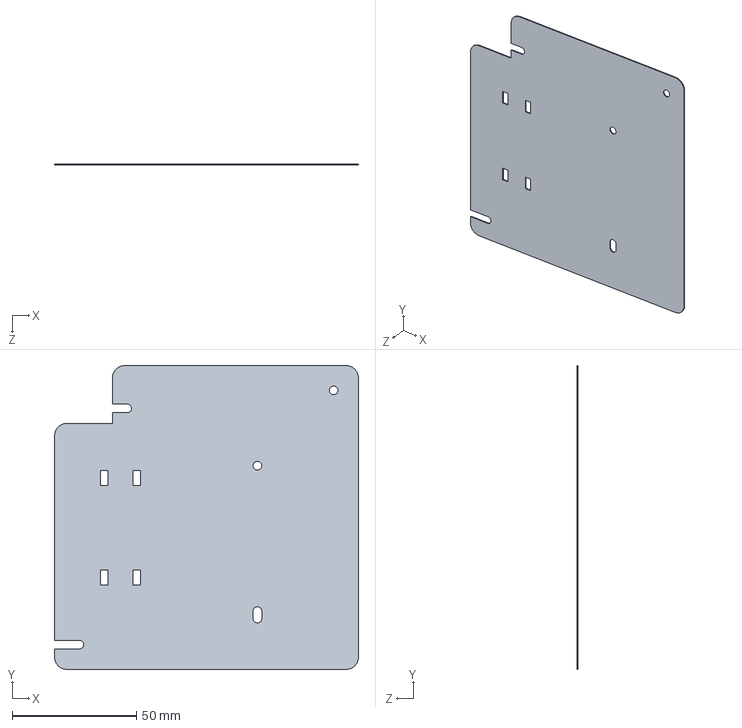
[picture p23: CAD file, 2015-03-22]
solidworks/printer-adapted-sensor/printer-adapted-circuit-plate.SLDPRT
122.2 x 122.2 x 0.444 mm

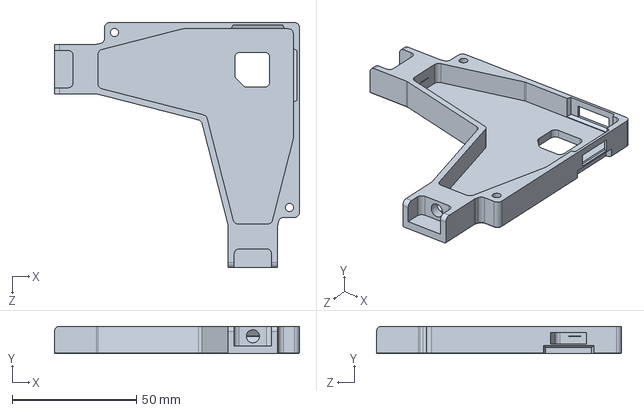
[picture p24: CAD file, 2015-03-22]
solidworks/2-axis-prototype/Chassis.SLDPRT
98.5 x 11.0 x 98.5 mm

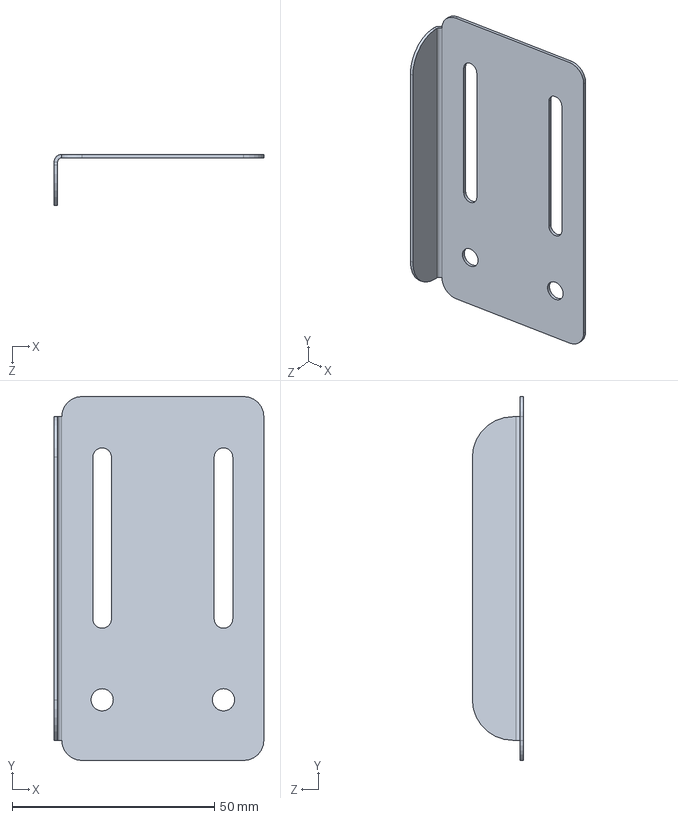
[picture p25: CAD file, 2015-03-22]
solidworks/printer-adapted-sensor/printer-adapted-mounting-bracket.SLDPRT
51.9 x 90.0 x 12.7 mm

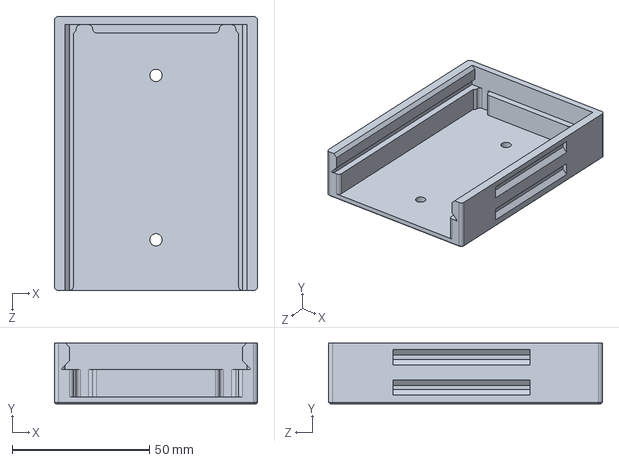
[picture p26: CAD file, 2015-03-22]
solidworks/printer-adapted-sensor/printer-adapted-circuit-case.SLDPRT
74.2 x 22.1 x 100.0 mm

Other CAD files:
solidworks/2-axis-simulator/2-axis-simulator model.SLDPRT
solidworks/2-axis-prototype/Lid.SLDPRT
solidworks/2-axis-prototype/Lid Insert.SLDPRT
solidworks/printer-adapted-sensor/printer-adapted-filament-attachment-bottom.STL
solidworks/2-axis-prototype/Chassis.STL
solidworks/2-axis-prototype/Lid Insert Var0.STL
solidworks/2-axis-prototype/Lid Insert Var1.STL
solidworks/2-axis-prototype/Lid Insert.STL
solidworks/2-axis-prototype/Lid.STL
solidworks/printer-adapted-sensor/Mirrorprinter-adapted-lid.SLDPRT
solidworks/printer-adapted-sensor/printer-adapted-chassis.SLDPRT
solidworks/single-axis-prototype/main-section.SLDPRT
solidworks/single-axis-prototype/top-section.SLDPRT

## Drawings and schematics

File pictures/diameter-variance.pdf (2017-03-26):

## Filament Diameter Variance

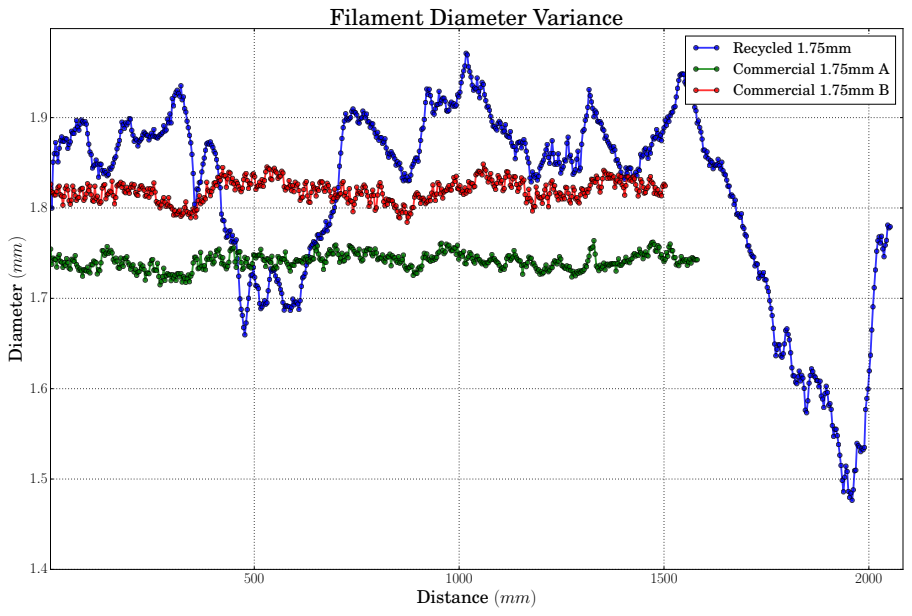
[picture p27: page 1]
Distance (mm); Diameter; Recycled 1.75mm Commercial 1.75mm A Commercial 1.75mm B

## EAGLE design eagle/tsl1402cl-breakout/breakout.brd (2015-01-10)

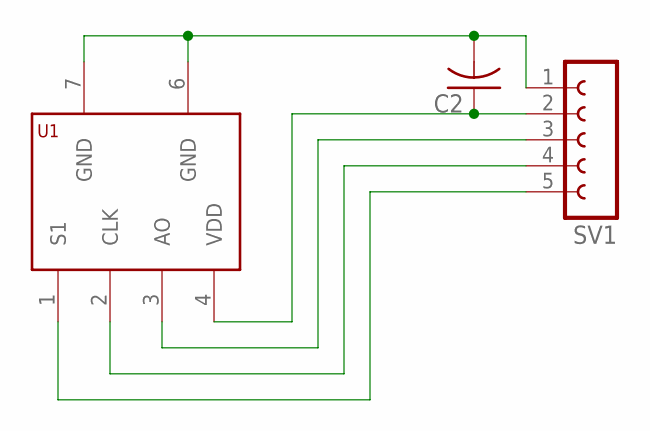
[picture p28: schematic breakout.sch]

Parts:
C2: C-US025-030X050; C025-030X050
SV1: FE05-1
U1: TSL1401CL; TSL8

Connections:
unnamed: C2.2, SV1.1, U1.6 (GND), U1.7 (GND)
unnamed: C2.1, SV1.2, U1.4 (VDD)
unnamed: SV1.3, U1.3 (AO)
unnamed: SV1.4, U1.2 (CLK)
unnamed: SV1.5, U1.1 (S1)

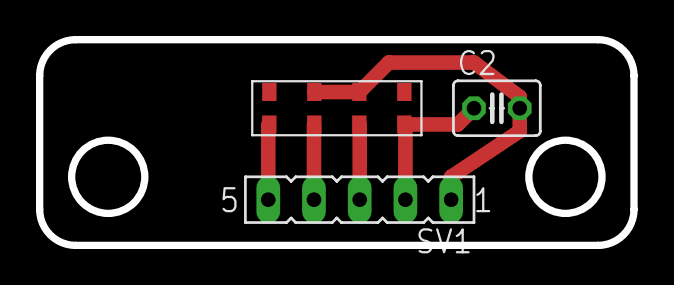
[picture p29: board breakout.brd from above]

Board: 2 copper layers, 33.0 x 11.4 mm, 3 parts (0 on the bottom side), 5 nets.

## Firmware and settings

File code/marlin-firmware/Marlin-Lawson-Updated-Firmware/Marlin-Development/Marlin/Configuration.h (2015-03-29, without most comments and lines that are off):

#define CONFIGURATION_H
#include "boards.h"
#define STRING_VERSION "1.0.2"
#define STRING_URL "reprap.org"
#define STRING_VERSION_CONFIG_H __DATE__ " " __TIME__ // build date and time
#define STRING_CONFIG_H_AUTHOR "(none, default config)" // Who made the changes.
#define STRING_SPLASH_LINE1 "v" STRING_VERSION // will be shown during bootup in line 1
#define SERIAL_PORT 0
#define BAUDRATE 250000
  #define MOTHERBOARD BOARD_RUMBA
#define EXTRUDERS 2
#define POWER_SUPPLY 1
#define TEMP_SENSOR_0 5
#define TEMP_SENSOR_1 5
#define TEMP_SENSOR_2 0
#define TEMP_SENSOR_3 0
#define TEMP_SENSOR_BED 1
#define MAX_REDUNDANT_TEMP_SENSOR_DIFF 10
#define TEMP_RESIDENCY_TIME 5  // (seconds)
#define TEMP_HYSTERESIS 5       // (degC) range of +/- temperatures considered "close" to the target one
#define TEMP_WINDOW     5       // (degC) Window around target to start the residency timer x degC early.
#define HEATER_0_MINTEMP 5
#define HEATER_1_MINTEMP 5
#define HEATER_2_MINTEMP 5
#define HEATER_3_MINTEMP 5
#define BED_MINTEMP 5
#define HEATER_0_MAXTEMP 275
#define HEATER_1_MAXTEMP 275
#define HEATER_2_MAXTEMP 275
#define HEATER_3_MAXTEMP 275
#define BED_MAXTEMP 150
#define PIDTEMP
#define BANG_MAX 255 // limits current to nozzle while in bang-bang mode; 255=full current
#define PID_MAX BANG_MAX // limits current to nozzle while PID is active (see PID_FUNCTIONAL_RANGE below); 255=full current
  #define PID_FUNCTIONAL_RANGE 10 // If the temperature difference between the target temperature and the actual temperature
  #define PID_INTEGRAL_DRIVE_MAX PID_MAX  //limit for the integral term
  #define K1 0.95 //smoothing factor within the PID
  #define PID_dT ((OVERSAMPLENR * 10.0)/(F_CPU / 64.0 / 256.0)) //sampling period of the temperature routine
    #define  DEFAULT_Kp 22.2
    #define  DEFAULT_Ki 1.08
    #define  DEFAULT_Kd 114
#define MAX_BED_POWER 255 // limits duty cycle to bed; 255=full current
#define PREVENT_DANGEROUS_EXTRUDE
#define PREVENT_LENGTHY_EXTRUDE
#define EXTRUDE_MINTEMP 170
#define EXTRUDE_MAXLENGTH (X_MAX_LENGTH+Y_MAX_LENGTH) //prevent extrusion of very large distances.
#define ENDSTOPPULLUP_XMAX
#define ENDSTOPPULLUP_YMAX
#define ENDSTOPPULLUP_ZMAX
#define ENDSTOPPULLUP_XMIN
#define ENDSTOPPULLUP_YMIN
#define ENDSTOPPULLUP_ZMIN
const bool X_MIN_ENDSTOP_INVERTING = true; // set to true to invert the logic of the endstop.
const bool Y_MIN_ENDSTOP_INVERTING = true; // set to true to invert the logic of the endstop.
const bool Z_MIN_ENDSTOP_INVERTING = true; // set to true to invert the logic of the endstop.
const bool X_MAX_ENDSTOP_INVERTING = true; // set to true to invert the logic of the endstop.
const bool Y_MAX_ENDSTOP_INVERTING = true; // set to true to invert the logic of the endstop.
const bool Z_MAX_ENDSTOP_INVERTING = true; // set to true to invert the logic of the endstop.
#define X_ENABLE_ON 0
#define Y_ENABLE_ON 0
#define Z_ENABLE_ON 0
#define E_ENABLE_ON 0 // For all extruders
#define DISABLE_X false
#define DISABLE_Y false
#define DISABLE_Z false
#define DISABLE_E false // For all extruders
#define DISABLE_INACTIVE_EXTRUDER true //disable only inactive extruders and keep active extruder enabled
#define INVERT_X_DIR true
#define INVERT_Y_DIR true
#define INVERT_Z_DIR true
#define INVERT_E0_DIR true
#define INVERT_E1_DIR false
#define INVERT_E2_DIR false
#define INVERT_E3_DIR false
#define X_HOME_DIR 1
#define Y_HOME_DIR -1
#define Z_HOME_DIR 1
#define min_software_endstops false // If true, axis won't move to coordinates less than HOME_POS.
#define max_software_endstops false  // If true, axis won't move to coordinates greater than the defined lengths below.
#define X_MIN_POS 0
#define Y_MIN_POS 0
#define Z_MIN_POS 0
#define X_MAX_POS 300
#define Y_MAX_POS 350
#define Z_MAX_POS 200
#define X_MAX_LENGTH (X_MAX_POS - X_MIN_POS)
#define Y_MAX_LENGTH (Y_MAX_POS - Y_MIN_POS)
#define Z_MAX_LENGTH (Z_MAX_POS - Z_MIN_POS)
#define Z_PROBE_REPEATABILITY_TEST  // If not commented out, Z-Probe Repeatability test will be included if Auto Bed Leveling is Enabled.
#define NUM_AXIS 4 // The axis order in all axis related arrays is X, Y, Z, E
#define HOMING_FEEDRATE {50*60, 50*60, 6*60, 0}  // set the homing speeds (mm/min)
#define DEFAULT_AXIS_STEPS_PER_UNIT   {80,80,120.906,95}  // default steps per unit for Ultimaker
#define DEFAULT_MAX_FEEDRATE          {200, 200, 5, 25}    // (mm/sec)
#define DEFAULT_MAX_ACCELERATION      {5000,5000,500,10000}    // X, Y, Z, E maximum start speed for accelerated moves. E default values are good for Skeinforge 40+, for older versions raise them a lot.
#define DEFAULT_ACCELERATION          3000    // X, Y, Z and E acceleration in mm/s^2 for printing moves
#define DEFAULT_RETRACT_ACCELERATION  3000   // E acceleration in mm/s^2 for retracts
#define DEFAULT_TRAVEL_ACCELERATION   3000    // X, Y, Z acceleration in mm/s^2 for travel (non printing) moves
#define DEFAULT_XYJERK                5.0    // (mm/sec)
#define DEFAULT_ZJERK                 0.4     // (mm/sec)
#define DEFAULT_EJERK                 5.0    // (mm/sec)
#define CUSTOM_M_CODES
  #define CUSTOM_M_CODE_SET_Z_PROBE_OFFSET 851
  #define Z_PROBE_OFFSET_RANGE_MIN -15
  #define Z_PROBE_OFFSET_RANGE_MAX -5
#define EEPROM_SETTINGS
#define EEPROM_CHITCHAT
#define PLA_PREHEAT_HOTEND_TEMP 180
#define PLA_PREHEAT_HPB_TEMP 70
#define PLA_PREHEAT_FAN_SPEED 0   // Insert Value between 0 and 255
#define ABS_PREHEAT_HOTEND_TEMP 240
#define ABS_PREHEAT_HPB_TEMP 110
#define ABS_PREHEAT_FAN_SPEED 0   // Insert Value between 0 and 255
#define DISPLAY_CHARSET_HD44780_JAPAN     // "ääööüüß23°"
#define REPRAP_DISCOUNT_FULL_GRAPHIC_SMART_CONTROLLER
 #define DOGLCD
 #define U8GLIB_ST7920
 #define REPRAP_DISCOUNT_SMART_CONTROLLER
 #define ULTIPANEL
 #define NEWPANEL
  #define SDSUPPORT
  #define ULTRA_LCD
    #define LCD_WIDTH 22
    #define LCD_HEIGHT 5
#  define DEFAULT_LCD_CONTRAST 32
#define SOFT_PWM_SCALE 0
#define I2C_FILAMENT_SENSOR
#define FILAMENT_SENSOR_EXTRUDER_NUM	1  //The number of the extruder that has the filament sensor (0,1,2)
#define MEASUREMENT_DELAY_CM			60  //measurement delay in cm.  This is the distance from filament sensor to middle of barrel
#define DEFAULT_NOMINAL_FILAMENT_DIA  1.75  //Enter the diameter (in mm) of the filament generally used (3.0 mm or 1.75 mm) - this is then used in the slicer software.  Used for sensor reading validation
#define MEASURED_UPPER_LIMIT          3.0  //upper limit factor used for sensor reading validation in mm
#define MEASURED_LOWER_LIMIT          1.0  //lower limit factor for sensor reading validation in mm
#define MAX_MEASUREMENT_DELAY		   70  //delay buffer size in bytes (1 byte = 1cm)- limits maximum measurement delay allowable (must be larger than MEASUREMENT_DELAY_CM  and lower number saves RAM)
#define DEFAULT_MEASURED_FILAMENT_DIA  DEFAULT_NOMINAL_FILAMENT_DIA  //set measured to nominal initially
#define FILAMENT_LCD_DISPLAY
#include "Configuration_adv.h"
#include "thermistortables.h"

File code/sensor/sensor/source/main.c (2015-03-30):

#include "main.h"

char buffer[60];
int32_t xPixels[TSL_PIXEL_COUNT];
int32_t yPixels[TSL_PIXEL_COUNT];

uint16_t MAIN_AveragingIterations = MAIN_DEFAULT_AVERAGING;
FunctionalState MAIN_SensorState = DISABLE;
float MAIN_FilamentDiameter_MM = 1.33f;
float MAIN_NominalFilamentDiameter_MM = 1.75f;
const uint16_t MAIN_FilamentBufferDistance_MM = (600U);

/* Computes an IIR filtered filament diameter to prevent step changes to measured values */
float MAIN_IIRFilter(float input)
{
	float currentValue = ((MAIN_IIR_FILTER_SAMPLES-MAIN_IIR_FILTER_INPUT_WEIGHT)*MAIN_FilamentDiameter_MM);
	float newValue = (MAIN_IIR_FILTER_INPUT_WEIGHT)*input;
	return (currentValue + newValue) / MAIN_IIR_FILTER_SAMPLES;
}

int main()
{
	USART1_Init(USART1_BAUDRATE);
	Delay_Init();
	TSL_Init();
	LED_Init();
	DAC_SingleValue_Setup();
	I2C_Config();
	BUFF_InitializeBuffer();

	MAIN_SetSensorState(ENABLE);
	uprintf("Initializing sensor\r\n");

	while(1)
	{
		if (MAIN_SensorState == ENABLE)
		{
			uint16_t i;
			EdgeData x_edge_sum = {0,0,0,1};
			EdgeData y_edge_sum = {0,0,0,1};
			for (i = 1; i < MAIN_AveragingIterations+1; i++)
			{
				/* Measure the pixel array sensors and determine the shadow edges */
				TSL_MeasurePixels(xPixels, yPixels);
				EdgeData edge_x = DET_MicronsBetweenEdges(xPixels);
				EdgeData edge_y = DET_MicronsBetweenEdges(yPixels);

				if (edge_x.IsValid && edge_y.IsValid)
				{
					/* Add the x-result to the sum */
					x_edge_sum.E0    += edge_x.E0;
					x_edge_sum.E1    += edge_x.E1;
					x_edge_sum.Width += edge_x.Width;

					/* Add the y-result to the sum */
					y_edge_sum.E0    += edge_y.E0;
					y_edge_sum.E1    += edge_y.E1;
					y_edge_sum.Width += edge_y.Width;
				}
				else
				{
					uprintf("Sensor invalid\r\n");
					i -= 1; /* Reject the measurement */
				}
				/* Display the filament validity detection on the LEDs */
				LED_Write(2, (BitAction)(edge_x.IsValid));
				LED_Write(3, (BitAction)(edge_y.IsValid));

				/* Check the I2C bus to see if a command was recieved */
				//I2C_CheckReceive();
			}

			/* Divide the sum by the number of sampling iterations to get the averaged data */
			x_edge_sum.E0    *= (TSL_PIXEL_SPACING_NM / 1000.0f / 1000.0f) / (float)MAIN_AveragingIterations;
			x_edge_sum.E1    *= (TSL_PIXEL_SPACING_NM / 1000.0f / 1000.0f) / (float)MAIN_AveragingIterations;
			x_edge_sum.Width /= (float)MAIN_AveragingIterations;
			y_edge_sum.E0    *= (TSL_PIXEL_SPACING_NM / 1000.0f / 1000.0f) / (float)MAIN_AveragingIterations;
			y_edge_sum.E1    *= (TSL_PIXEL_SPACING_NM / 1000.0f / 1000.0f) / (float)MAIN_AveragingIterations;
			y_edge_sum.Width /= (float)i;

			/* Compute the filament diameter */
			float diameter = GEO_Filament_Diameter_MM(x_edge_sum, y_edge_sum);
			/* Update the most recent filament diameter measurement */			
			//MAIN_FilamentDiameter_MM = diameter;
			MAIN_FilamentDiameter_MM = MAIN_IIRFilter(diameter);
			uprintf("Diameter: %f\r\n", diameter);
			cprintf("Diameter %f\r\n", diameter);
			/* Set analog output to converted filament diameter */
			DAC_SetChannel1Data(DAC_Align_12b_R, (uint16_t)((diameter*1000.0)*(4096.0/3000.0)));
		}
		else
		{
			uprintf("Sensor disabled\r\n");
			DelayMs(1000);
			/* Check the I2C bus to see if data was received */
			//I2C_CheckReceive();
		}
	}
}

/* Change the state of the sensor */
void MAIN_SetSensorState(FunctionalState state)
{
	MAIN_SensorState = state;
	LED_Write(0, (BitAction)state);
	LED_Write(1, (BitAction)state);
}

//****************************************************************************

#ifdef  USE_FULL_ASSERT
/**
* @brief  Reports the name of the source file and the source line number
*         where the assert_param error has occurred.
* @param  file: pointer to the source file name
* @param  line: assert_param error line source number
* @retval None
*/
void assert_failed(uint8_t* file, uint32_t line)
{
	/* User can add his own implementation to report the file name and line number,
	ex: printf("Wrong parameters value: file %s on line %d\r\n", file, line) */

	/* Infinite loop */
	while (1)
	{
	}
}
#endif

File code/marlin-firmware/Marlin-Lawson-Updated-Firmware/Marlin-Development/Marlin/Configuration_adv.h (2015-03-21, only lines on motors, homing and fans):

#define CONTROLLERFAN_PIN 8 //Pin used for the fan to cool controller (-1 to disable)
#define EXTRUDER_0_AUTO_FAN_PIN -1
#define EXTRUDER_1_AUTO_FAN_PIN -1
#define EXTRUDER_2_AUTO_FAN_PIN -1
#define EXTRUDER_3_AUTO_FAN_PIN -1
#define ENDSTOPS_ONLY_FOR_HOMING // If defined the endstops will only be used for homing
#define X_HOME_RETRACT_MM 8
#define Y_HOME_RETRACT_MM 8
#define Z_HOME_RETRACT_MM 7
#define HOMING_BUMP_DIVISOR {1, 1, 2}  // Re-Bump Speed Divisor (Divides the Homing Feedrate)
#define MICROSTEP1 LOW,LOW
#define MICROSTEP2 HIGH,LOW
#define MICROSTEP4 LOW,HIGH
#define MICROSTEP8 HIGH,HIGH
#define MICROSTEP16 HIGH,HIGH
#define MICROSTEP_MODES {16,16,16,16,16} // [1,2,4,8,16]
#define DIGIPOT_MOTOR_CURRENT {135,135,135,135,135} // Values 0-255 (RAMBO 135 = ~0.75A, 185 = ~1A)
#define DIGIPOT_I2C_MOTOR_CURRENTS {1.0, 1.0, 1.0, 1.0, 1.0, 1.0, 1.0, 1.0}

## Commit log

2014-12-26 Initial code commit
    Added edge detector code
    [configuration.h]
2015-01-05 Added support for external ADC
    [configuration.h]
2015-01-05 Added solidworks model for single axis prototype
    [main-section.SLDPRT, top-section.SLDPRT]
2015-01-05 Moved arduino code into separate folder
    [configuration.h]
2015-01-05 Added initial commit of STM32F3 code
    When optimization is set to Ofast measurement frequency is ~16ksps
2015-01-08 Added led-bar solidworks files
    [main-section.SLDPRT, top-section.SLDPRT]
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2015-01-09 Revert "Added new stm32f3 solution files"
    This reverts commit 59841e8545f10ac5b27632c7f518e71ee6c6ccc7.
    [dac-output.c, edge-detection.h, led-bar.c]
2015-01-10 Created an updated breakout PCB for the TSL1401CL sensor
    Used EAGLE CAD to design a breakout board PCB for the TSL1401CL sensor.
    Eight of the breakout boards are being fabricated on the LPKF protomat
    PCB mill.
    The breakout boards will be used to develop several 2-axis filament
    sensor prototypes over the next few weeks.
    The breakout board pinout can be found in the datasheet for the
    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
    [breakout.brd, breakout.sch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]
2015-01-10 Added firmware support for the STM32F3's integrated programmable gain amplifier
    Firmware support for the STM32F3 programmable gain amplifier has been
    added.
    The programmable gain amplifier can be configured in non-inverting
    configuration with a selectable gain of 2, 4, 8, or 16.
    I was not able to get the amplifier to work as a differentiator since it
    cannot be configured in an inverting configuration.
    Right now the code has commented out references to the amplifier. It
    could potentially be used as a form of output later in this project.
    [main.c, opamp.c, tsl1401cl.c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]
2015-01-12 Added lots of documentation and datasheets, soldered PCBs
    Designed TSL1401Cl breakout boards in EAGLE and milled eight of them in
    the project lab PCB mill. Soldered five of the boards and four of them
    are working, one appears to have a short circuit possibly caused by
    inaccessible solder paste or excessive heat when soldering.
    I wrote the pinout on the breakout boards, but the pins can also be
    found in the TSL1401CL datasheet.
    I added a wealth of documentation pertaining the the STM32F3 and
    TSL1401CL sensor in a new folder on the Github repository. The STM32
    documentation is useful because it gives an overview of the STM32F3
    peripherals, and there are examples on how to initialize peripher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
2015-01-15 Added additional STM32F3 reference documentation
    Added "The Insiders Guide to STM32F3" to the documentation folder of the
    repository. This gives a broad overview of how STMicroelectronics has
    integrated their peripherals with the Cortex M4 core
2015-01-15 Changed one comment in the TSL module
    Updated the function comment for the TSL module to be more clear.
    Explains how the function starts an output cycle for the TSL1401CL
    sensor. For a full description of how the TSL1401CL sensor works,
    consult the datasheet in the reference documentation folder.
2015-01-15 Created a two-axis filament diameter sensor simulator in C#
    Developed a graphical simulator in C# to visualize the two-axis edge
    detection sensor.
    [Instructions]
    The LEDs, sensors, and filament can be moved by dragging and dropping
    the shapes. To constrain movement to be vertical, hold the 'Z' key when
    dragging. To constrain movement to be horizontal, hold the 'X' key.
    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
2015-01-15 Added error statistics to simulator
    Improved the simulator to display error statistics about the estimated
    filament diameter and corresponding cross sectional area.
    The current naive diameter calculation algorithm has an error of under
    5% at close range (~50mm), which decays to less than 2% at distances
    greater than 80mm.
2015-01-19 Made a simulator in Solidworks
    [2-axis-simulator model.SLDPRT]
2015-01-24 Renamed and added some stm32f3 documentation
    Added documentation for the stm32f3 standard peripheral library that is
    supplied by STMicroelectronics. This documentation provides information
    on using the peripheral library to interface with the stm32f3
    peripherals in C code. Renamed some of the other reference document
    files to conform to standard convention
2015-01-26 Initial commit of 2-axis prototype sensor CAD files
    Assembly
    - Chassis
    - Lid
    [Assembly.SLDASM, Chassis.SLDPRT, Chassis.STL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]
2015-02-08 Significant rework of the simulator
    Made significant changes to the shadow handling in the 2-axis sensor
    simulator.
    The previous method for calculating the shadow location was to compute
    the slope between the led and the filament and then draw a line. The
    line was then extended from the filament to the sensor's surface. This
    was inaccurate in part because it did not select the correct point on
    the filament, but also because the slope calculations should have been
    inverted for one of the axes. This caused a bit of floating point error
    in one of the axes. The short version is that the old way of handing
    shadows was complex and had errors.
    I've now deleted the old shadow code and replaced it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
2015-02-09 Updated 2-axis model
    Tweaked the lid's rim offset from 0.2mm to 0.3mm to make assembly
    easier.
    Added a lid insert that restricts inserted filament to the sensor's
    maximum range.
    Keyed the lid and chassis's filament hole so that the lid insert is
    always aligned.
    [Assembly.SLDASM, Chassis.SLDPRT, Lid Insert.SLDPRT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]
2015-02-09 Added Matlab code used to generate some 2-axis math
    Finds the symbolic representation of the intersection of the two
    filament-center-lines. This point gives the coordinates (fil_x, fil_y)
    of the filament's center.
2015-02-12 Initial commit of 2-axis diameter geometry math
    Added geometry.h and geometry.c . Contains the math needed to convert
    shadow edge positions to filament diameter. Currently uses trig
    functions: not fully optimized for floating point operations.
    Two options for diameter averaging (since the 2-axis sensor reads the
    width from two perpendicular directions):
    - Elliptical mean: assumes the filament is an ellipse, with the two
    diameters measured being the major and minor axis of the ellipse.
    Returns the diameter of a circle with the same area as this ellipse.
    - Mean: Returns the average of the two diameters.
    Current issues:
    - Requires as input the positions of the shadow edges in nm (integer)
    fro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
    [geometry.h]
2015-02-12 Revert "Initial commit of 2-axis diameter geometry math"
    This reverts commit dee4b4a718e5d217a961d3bdd8144f5a0bca2bbd.
    [geometry.h]
2015-02-12 Re-initial commit of 2-axis math
    from the sensor or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
    [geometry.h]
2015-02-12 Updated 2-axis math to take floats as input
    2-axis math (geometry.c) now takes in float variables (the positions of
    the shadows along the TSL1401 sensor). The offsets of the TSL's from the
    filament sensor's origin were added as constants to geometry.h .
    This allows the 2-axis math to be used with the current sub-pixel
    function.
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2015-02-14 Added support for dual ADC measurements
    The STM32F3 contains two fast ADCs, ADC1 and ADC2, which are tightly
    coupled and can be utilized in a master-slave configuration. Both ADCs
    can be triggered to start a conversion simultaneously and the conversion
    value can be read in parallel.
    I've changed the initialization functions for the ADC peripherals so
    that they operate in Regular Simultaneous Mode, which will allow us to
    read both sensor axes at the same time.
    I've also configured the ADCs to operate nearly 10 times faster. I found
    several optimizations in the reference documents and updated the code to
    make use of them. They should be operating at 5Msps.
    [tsl1401cl.c, tsl1401cl.h]
2015-02-14 Revert "Minor refactor of GEO module"
    This reverts commit c43f08f81f811c04336f6d19f8d5d6ee2f59607c.
    [geometry.h]
2015-02-14 Minor refactor of GEO module
    Fixed incorrect files being committed in last commit
    [geometry.h]
2015-02-14 Moved geometry.h and geometry.c to the correct source code folder
    Sorry, Rowan. I hope you don't have uncommitted changes that will cause
    a merge conflict. I relocated the geometry files to the correct source
    code folder. Right now geometry.h cannot easily be imported by other
    source code files.
    [geometry.h]
2015-02-14 Changed GEO_Filament_Diameter to take advantage of DPS FPU instructions
    Modified some math in the GEO_Filament_Diameter function to take
    advantage of special FPU instructions that can reduce rounding error.
    The fmaf(x,y,z) returns x*y+z, where x*y is computed with infinite
    precision, and only the sum is subject to floating point rounding error.
    The compiler will replace all calls to the fmaf function call with a
    single 3-cycle VMLA.F32 ARM instruction.
    Using fmaf(x,y,z) will consume one extra cycle compared to not using
    fmaf, however the additional precision gained from reducing rounding
    error is well worth the speed tradeoff.
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2015-02-15 Changed some coordinates around in the geometry file
    Currently being debugged. Something is wrong
    [geometry.h]
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2015-02-22 Comment typo correction in geometry.h /.c
    [geometry.h]
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2015-02-26 Improved fit for 2-axis prototype's lid & insert
    Updated Solidworks models for 2-axis prototype: improved fit (via
    margins) and added a lid insert variation (see feature tree in "Lid
    Insert.SLDPRT") for holding a piece of 3mm filament steady, in the
    approximate center of the sensing area.
    [Assembly.SLDASM, Lid Insert Var0.STL, Lid Insert Var1.STL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]
2015-02-28 Geometry bug-fix and changes to two constants
    Corrected the inputs to geometry math: E1 and E0 for the B sensor were
    mixed up.
    Changed the number of iterations for sensor data averaging to 300.
    Changed the integration time for each reading to 0.
    Fixed the end condition for iteration counting.
    Deleted old geometry math code.
    [main.c, tsl1401cl.h]
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2015-03-09 Added 'large' configuration to 2-axis prototype.
    LED-sensor distance changed to 130mm.
    LED mounting changed to fit small high-brightness LEDs.
    Note: I noticed that some of the LED-sensor distances are not defined
    accurately for the previous 2-axis sensor prototype. I will be
    correcting these: should improve math accuracy.
    [Assembly.SLDASM, Chassis.SLDPRT, Lid Insert.SLDPRT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]
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2015-03-19 Fixed github commitment issues
    [dac.c, main.c]
2015-03-19 Revert "Fixed github commitment issues"
    This reverts commit ec6bfed7352a31c0173654c9b4af67792d0dcaec.
    [dac.c, main.c]
2015-03-20 Comment corrections in edge-detection
    [edge-detection.h]
2015-03-21 Fixed bugs with the I2C code
    Fixed several issues with the I2C code, and ended up porting most of the
    code from another I2C file that was used to communicate with the
    STM32F3's magnetic compass and gyroscope. The code was tested with a Bus
    Pirate and an Arduino, and after debugging issues with the Arduino Wire
    library, the I2C code now finally works.
    [i2c.c, i2c.h]
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2015-03-21 Reverted previous pin changes to TSL1401CL
    Last commit by Rowan replaced my previous pin changes, this commit
    undoes that change.
    [tsl1401cl.h]
2015-03-21 Uploaded Marlin firmware for Lawson printer
    [Configuration.h, Configuration_adv.h, Marlin Logo.dxf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]
2015-03-22 Added printer-adapted sensor prototype models
    Made 2 changes since printing and assembling the models:
    - Made the mounting protrusion on the printer-adapted-chassis longer (6
    -> 12mm) so that the next iteration will not need nylon standoffs to
    line up with the cold end.
    - Moved the clearance slots on the printer-adapted-board mount for the
    board's underside pins so that the board fits properly.
    [Assembly.SLDASM, Chassis-130mm.STL, Chassis.SLDPRT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]
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2015-03-23 Improved I2C slave code
    Improved code for acting as a slave in I2C communication. Uses polling
    functions found in the STM32 standard peripheral library instead of
    interrupt based functions. Tested communication with a Bus Pirate to
    verify correct I2C communication
    [i2c-commands.c, i2c.c, i2c.h]
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2015-03-23 Re-enabled I2C and USART in main.c
    [Configuration.h]
2015-03-24 Fixed bugs in both Box Filter functions
    In (old) BoxFilter: there used to be a bug where the averaged value for
    x[i] was subtracted from the moving sum instead of the old value for
    x[i].
    In (new) CenteredBoxFilter: the (M+1)th last value was never changed,
    where M is the box filter length. This lead to a large difference being
    picked up by the difference function, making an edge get detected nearly
    always at the edge of the sensor. This has been fixed and tested.
    Finally, the divisors used in each box filter was replaced with a
    constant integer, that we can change to 1 if we decide to make that
    optimization.
2015-03-24 Increased averaging iterations to 3000
    Increased default averaging iterations to 3000, up from 1. The sensor
    will now average 3000 measurements before computing the diameter,
    instead of only using a single measurement which is susceptible to noise
    [main.c, main.h]
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2015-03-25 Improved debugging output for I2C commands
    Moved uprintf calls to occur after an I2C response has been sent, to
    reduce command response latency when debugging output is enabled. Added
    an error command statement if the command was not recognized by the
    slave. Added COM_AVERAGING_SAMPLES handler to COM_ExecuteCommand
    [i2c-commands.c]
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2015-03-25 Updated Marlin firmware code and documented filament sensor code locations
    Uploaded the latest Marlin firmware code to the code folder. I
    documented and tagged all the locations in the code that need to be
    updated for the filament sensor code to work with I2C instead of Analog
    output. I also created two new files, i2c_filament_sensor.cpp and
    i2c_filament_sensor.h which contain methods for communicating with the
    STM32F3 via I2C. Hopefully these methods are all that is required for
    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
    [Configuration.h]
2015-03-25 added enph 459 tags to firmware
    [Configuration.h]
2015-03-26 Commented out debug statements in COM_SendMeasurement()
    After testing I2C communication, I noticed that writing debug statements
    to USART consumes so much CPU bandwidth that the STM32 board is unable
    to finish sending bytes via I2C before another I2C request is made.
    After commenting out references to the debug print statements, the STM32
    no longer encounters bandwidth errors.
    [i2c-commands.c]
2015-03-26 Fixed a header file import error
    Accidentally imported "i2c_filament_sensor.cpp" instead of
    "i2c_filament_sensor.h". This is now fixed.
2015-03-26 Added I2C support in Marlin firmware
    Line 857 in temperature.cpp was the crucial line. Replaced it with a
    single reference to FIL_RequestMeasurementI2C()
2015-03-27 Fixed bug in I2C code. Added interrupt support for I2C.
    Added interrupt based support for I2C code. This allows the device to
    respond much more quickly than with the previous polling based
    approached.
    [i2c-commands.c, i2c.c, i2c.h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]
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2015-03-29 Added custom Marlin support for I2C filament sensor
    [Configuration.h]
2015-03-29 bug fixes in i2c support
    [i2c-commands.c, main.c]
2015-03-30 Added IIR output filter to sensor
    The sensor will now filter the output (in addition to filtering the
    input pixel values). This IIR filter will prevent rapid step changes in
    filament diameter measurements. New measurements are now computed as:
    x_(i+1) = ((15*x_i) + (new measurement)) / 16, and the constants 15, 1,
    16 can be modified as define macros.
    [main.c, main.h]
2015-03-30 Fixed a bug that prevented FIL_LastExtruderPosition_MM from being reset
    Fixed a bug that prevented the sensor values from being updated when a
    second print was started. Previously, FIL_LastExtruderPosition_MM would
    not be reset when a new print was started, meaning that no new
    volumetric multipliers would be requested until the extruder position
    exceeded the highest extruder position of the previous print. To fix
    this, FIL_LastExtruderPosition_MM is now reset when a G92 gcode command
    is used to modify the extruder position. This is not a perfect solution
    and will likely cause issues with dual extrusion support.
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2017-03-26 Remove unnecessary arduino firmware
    [configuration.h]
